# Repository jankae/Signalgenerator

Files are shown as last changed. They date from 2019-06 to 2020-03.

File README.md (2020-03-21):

# Signalgenerator

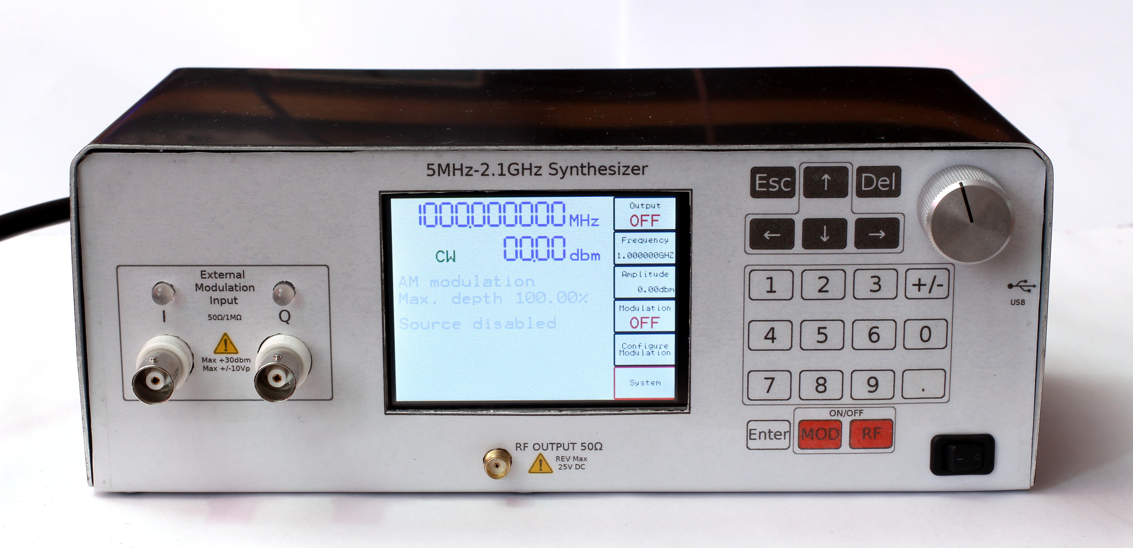
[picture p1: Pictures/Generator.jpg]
Generator


## What is it?
A homemade RF signal generator with these features:
* Frequency range: 5MHz to 2.1GHz
* Amplitude range: approx. -40dbm to +15dbm (slightly frequency dependent)
* Modulation
  * AM
  * FM
    * Up to 12.5MHz frequency deviation
  * QAM
    * Up to 32 constellation points
    * Up to 33M samples per second
    * Up to 36 samples per symbol
    * Pulse-shaping and differential encoding
  * External I/Q inputs
    * AC/DC coupling
    * Up to +30dbm/10Vpk input
    * Up to 10MHz of bandwidth
* Spectral purity@+10dbm:
  * Harmonic:
    * f >= 150MHz: <-30dbc
    * f >= 10MHz: <-25dbc
    * f < 10MHz: <-15dbc
  * Non-harmonic:
    * <-50dbc (limited by noise floor for lower output power)
  * Phase noise:
    * <-80dbc/Hz@10kHz offset

## Why was it build?
* Gain experience with RF circuit design
* Unwilling to pay the price for commercial generators (of course this one can't compete with a commercial one but should be good enough for simple RF experiments)

## How does it work?
For a high level overview see the description of the [RF generation](Documentation/RF.md).
For the effect of RF shielding see [these](Documentation/Shielding.md) measurements.

## More Pictures:
The inside: (I reused the frontpanel PCB from [this](https://github.com/jankae/battery-sim) project)
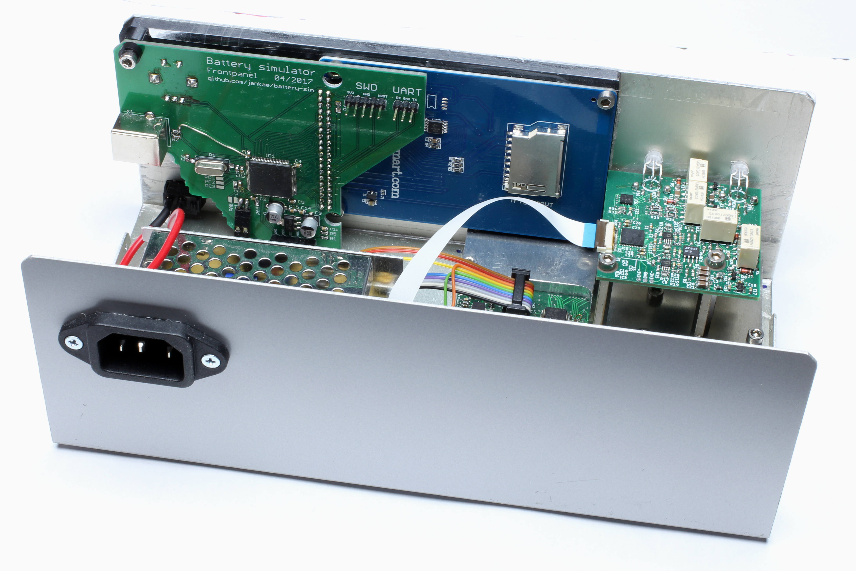
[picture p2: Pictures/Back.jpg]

The external modulation input PCB:
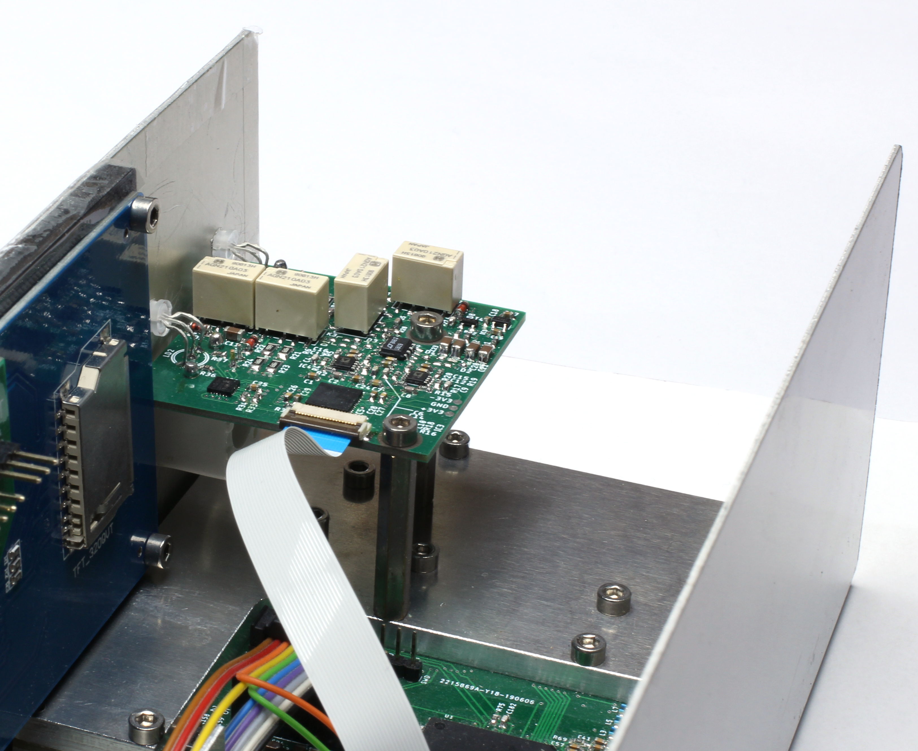
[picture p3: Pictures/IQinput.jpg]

The main RF board:


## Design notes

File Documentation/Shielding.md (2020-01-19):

# Shielding
The critical sections of the RF board are covered by a machined aluminium shield:
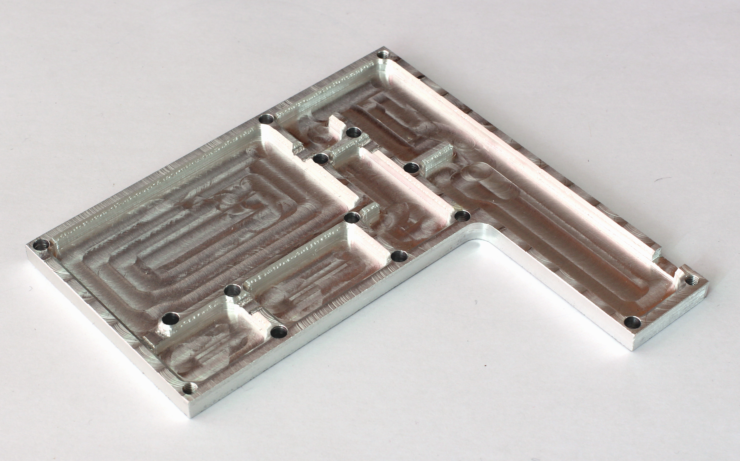
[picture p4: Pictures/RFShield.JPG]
RFshield

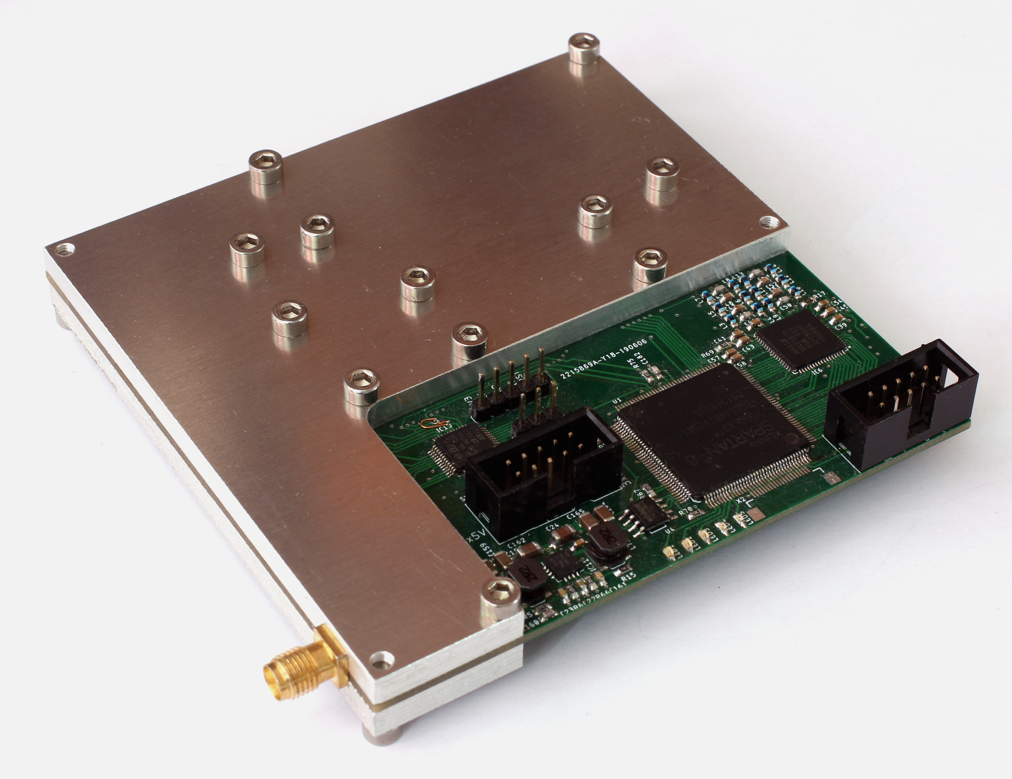
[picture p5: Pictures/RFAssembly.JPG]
RFassembly


The shield is supposed to block external RF from entering the signal generation, prevent emission of unwanted RF signals and shield the different sections from each other. Despite not having RF gaskets and thus probably not the best contact to the PCB ground, it improved the output signal quality significantly, especially unwanted tones when the output attenuation was high.

In the following measurements, the cyan trace shows the output signal without the shield, the yellow trace with the shield:
### 1GHz@0dbm:
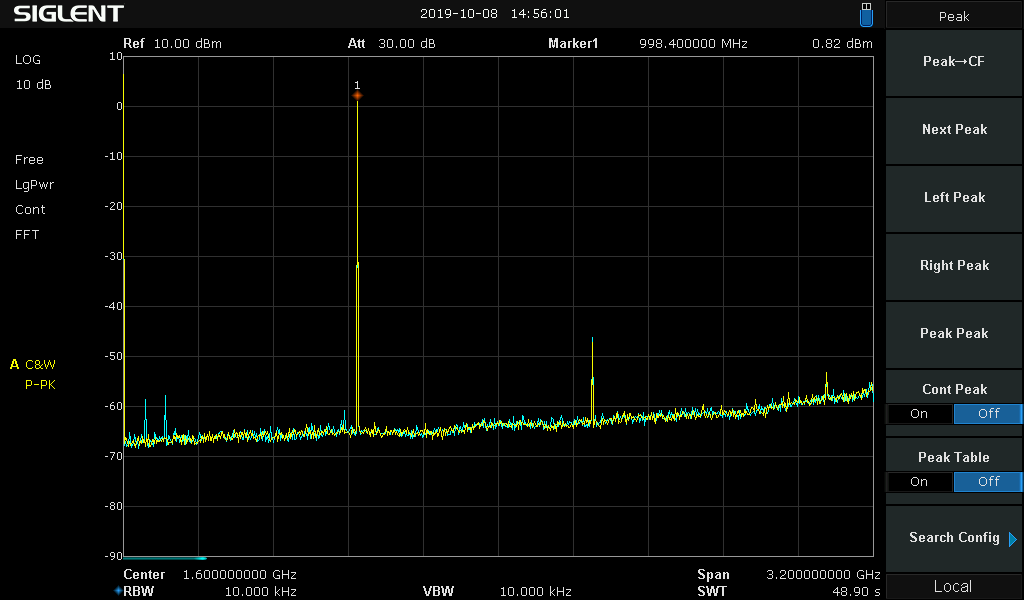
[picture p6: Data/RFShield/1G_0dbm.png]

If you zoom in, the phasenoise also improved slightly:
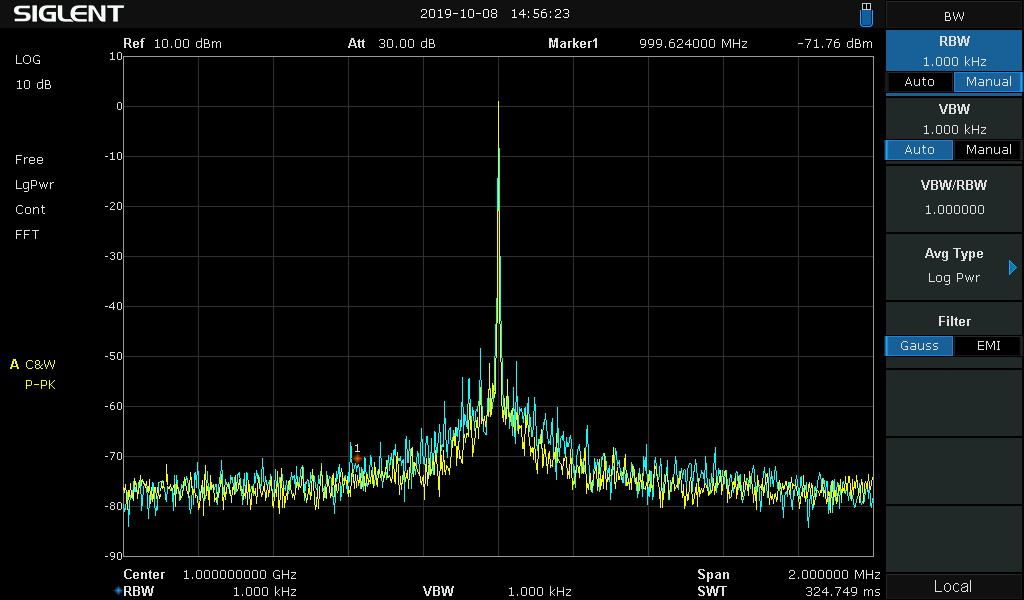
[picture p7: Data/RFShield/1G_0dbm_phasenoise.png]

### 1GHz@-30dbm:
The shield removes quite a few unwanted tones.
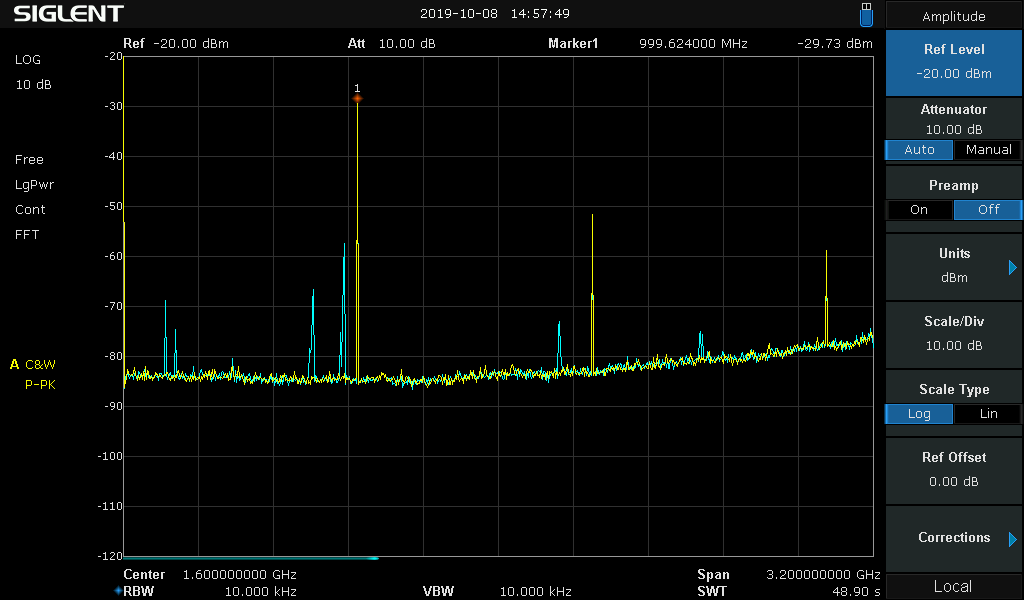
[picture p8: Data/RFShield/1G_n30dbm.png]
1G-30

### 100MHz@+10dbm:
Not much improvement here, the output driver already distorts quite a bit at this frequency and power.
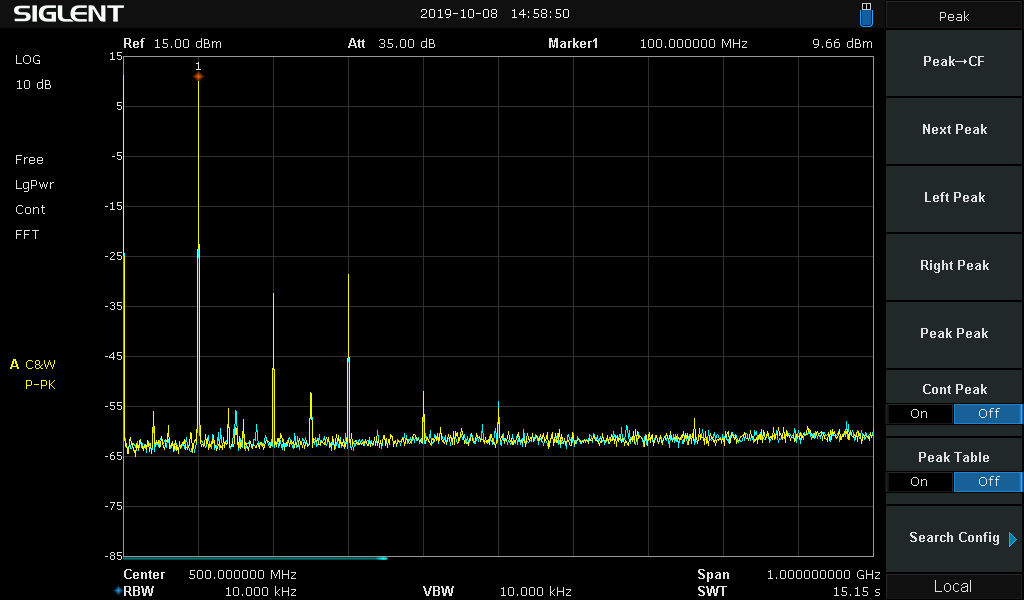
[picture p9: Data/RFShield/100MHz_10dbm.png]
100M+10

### 100MHz@-10dbm:
Again, the shield removes unwanted tones.
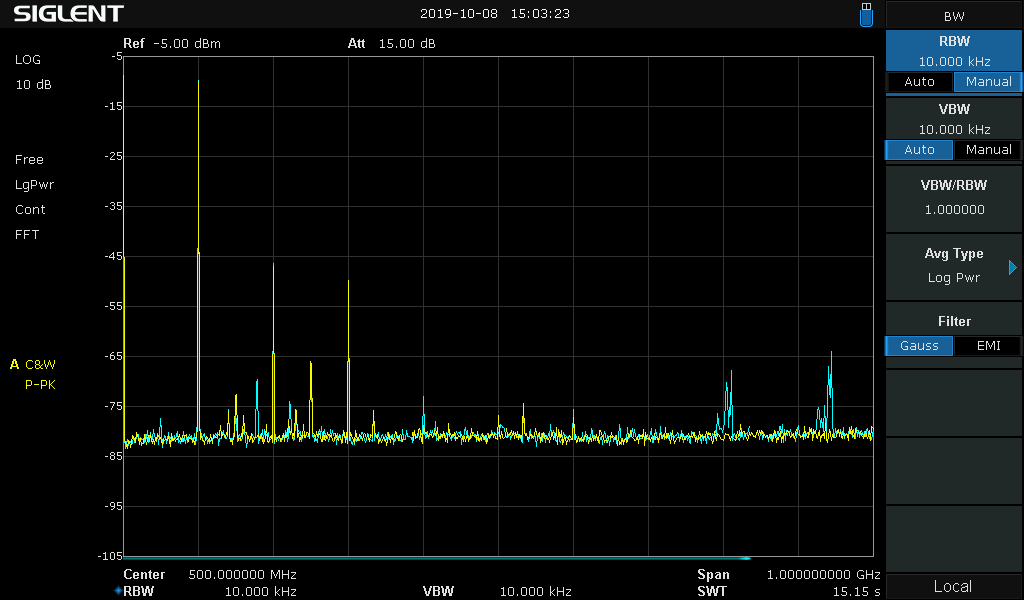
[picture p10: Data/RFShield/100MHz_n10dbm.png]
100M-10

### 100MHz@-30dbm:
Again, the shield removes unwanted tones.
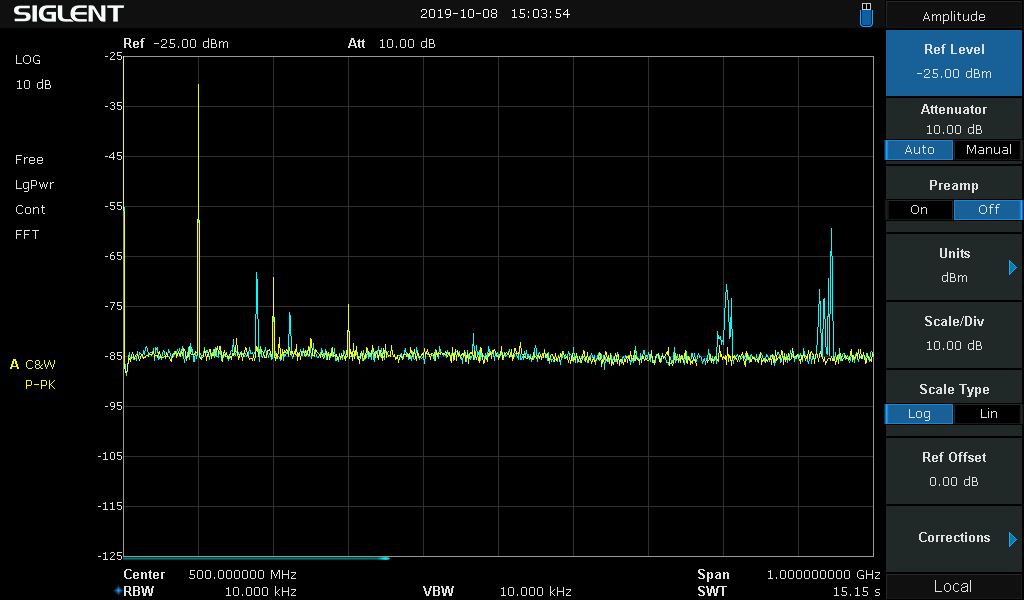
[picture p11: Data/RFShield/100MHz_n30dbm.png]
100M-30

### Output disabled:
Even with the output switched off, the noisefloor is not especially good. This is probably caused by the output amplifiers that are directly connected to the output (any attenuation is done before the final amplification).

During this measurement all PLLs, mixers and RF switches were turned off. The generated tones with no shield are external RF signals that are amplified by the output amplifier.
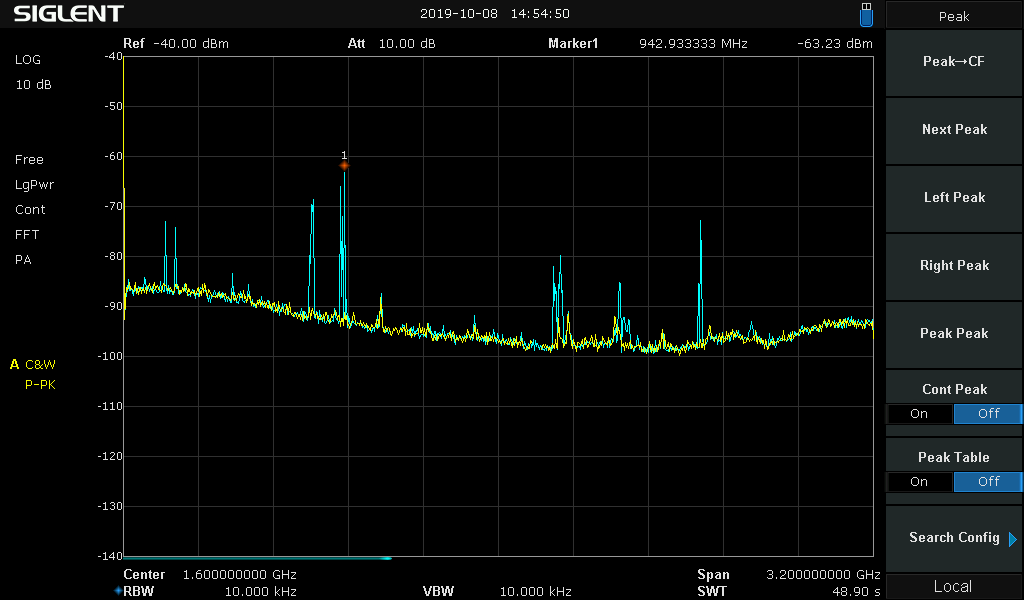
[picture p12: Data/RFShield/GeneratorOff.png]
output_off


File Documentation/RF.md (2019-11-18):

# RF Section
How does the synthesizer generate its signal? First, a blockdiagram of the RF section:
Blockdiagram of RF generation
The signal starts all the way on the left with the main PLL (MAX2871) which generates a sine wave with a frequency range of 250MHz to 2.1GHz. At the next stage some modulation is applied to the signal. In this case a HMC1097 I/Q modulator is used, which contains both mixers as well as the +/-45° phase shift of the carrier. The I/Q inputs are fed by a DAC which gets its signal from an FPGA. This configuration allows to generate pretty much any modulation desired.
After the modulation the signal is passed through a filter bank. Why is that necessary? The MAX2871 doesn't have a VCO covering the whole frequency range. Instead it divides down the VCO for lower output frequencies. This means there are a lot of harmonics still present in the signal. A filter is required that removes these harmonics. As the signal frequency can be changed instead of one filter a whole filter bank is needed.
How many filters are required? Assuming ideal lowpass filters, each filter could cover a frequency range of f to just below 2*f. Any wider and the second harmonic at f would also pass through. For this snythesizer this would mean four filters:

* 500MHz lowpass for 250MHz<=f<500MHz
* 1000MHz lowpass for 500MHz<=f<1000MHz
* 2000MHz lowpass for 1000MHz<=f<2000MHz
* 4000MHz lowpass for 2000MHz<=f<2100MHz

However, actual lowpass filters have a transition band in which the attenuation is low. The cutoff-frequency of each filter must therefor be quite a bit below the lowest possible second harmonic, leading to six filters for this design.
The number of filters is also the reason why the main PLL only goes down to 250MHz. Both the MAX2871 and the HMC1097 could handle lower frequencies, but that would require significantly more filters. Instead the signal is mixed with a fixed frequency of 1GHz from a second PLL for frequencies below 250MHz. In this case the main PLL is set to 1GHz above the actual output frequency . For example, a 100MHz output signal would be generated by setting the main PLL to 1.1GHz. After filtering the signal is down converted by the second PLL and its mixer to 100MHz. The mixer also produces the sum of the frequencies (in this case 2.1GHz) but this is easily filtered out by the following 250MHz lowpass.

All that is left to do is controlling the output level. Various attenuators before the final output amplifier stage are controlled by a microcontroller. Right at the output the signal is split and the weaker part of it fed back into a detector which is sampled by the microcontroller. This closes the level control loop (Initially a analog output level control with an opamp was used. This was actually faster and easier than the digital solution but didn't work well in combination with amplitude modulation. The level control circuit would try to compensate for the amplitude changes from the modulation).

The signal path can also be followed on this PCB overlay:
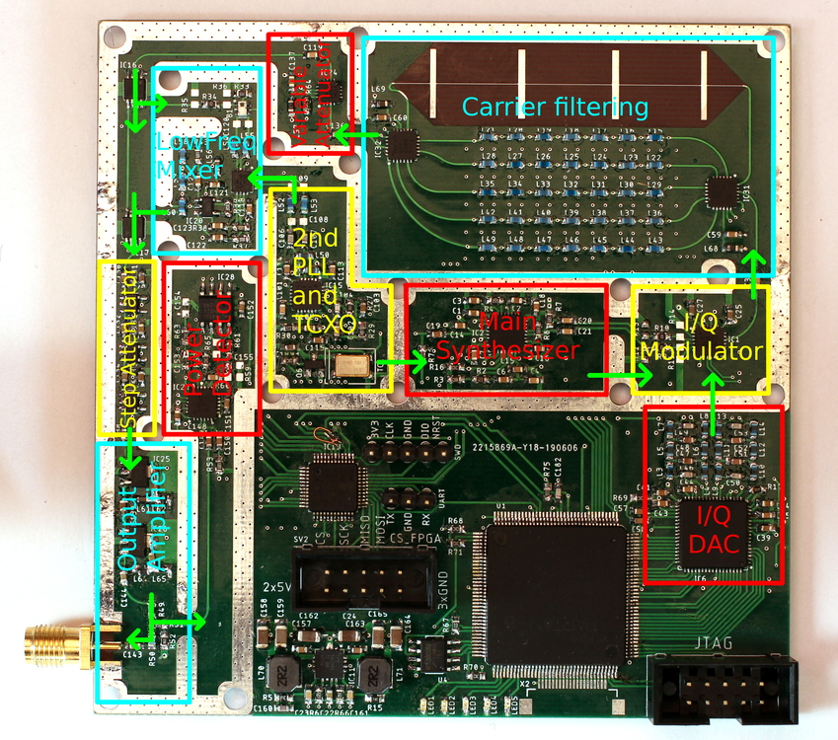
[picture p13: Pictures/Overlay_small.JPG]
RFOverlay


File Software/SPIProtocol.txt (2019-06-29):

Frontpanel to RF board:
0-7: Frequency in Hz, uint64_t. 0 if output disabled.
8-9: Amplitude in 1/100 dbm, int16_t.
10-11: Status bits, uint16_t.
        0x0001: Use internal reference
        0xFFFE: reserved
12-31: reserved

RF board to Frontpanel:
0-1: Status bits, uint16_t.
        0x0001: Internal reference on
        0x0002: Main PLL on
        0x0004: Unlock main PLL
        0x0008: Heterodyne PLL on
        0x0010: Unlock heterodyne PLL
        0x0020: I/Q Modulator enabled
        0x01C0: Selected Filter:
            000: 340MHz
            001: 500MHz
            010: 750MHz
            011: 1.1GHz
            100: 1.7GHz
            101: 2.5GHz
            110-111: reserved
        0x0200: 1st 15dbm attenuator enabled
        0x0400: 2nd 15dbm attenuator enabled
        0x0800: 3rd 15dbm attenuator enabled
        0x1000: Amplitude unlevel
        0xE000: reserved
2-3: reserved
4-7: 0xAE795C0D, magic constant to check communication
8-31: reserved

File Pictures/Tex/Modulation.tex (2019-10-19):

\documentclass[border=10pt]{standalone}  
\usepackage{tikz}
\usepackage[american,siunitx]{circuitikzgit}
\usetikzlibrary{arrows,calc,positioning,decorations.markings}

\newcommand{\divider}[1] 
{  % #1 = name 
\begin{scope}[transform shape]
\draw[thick] (#1)node[](a){} +(-12pt,-12pt) rectangle +(12pt,12pt);
\draw (a)+(12pt, 12pt)--+(-12pt,-12pt);
\draw (a)+(-5pt,6pt) node[](){\footnotesize -45};
\draw (a)+(4pt,-7pt) node[](){\footnotesize +45};
\end{scope}
}

\newcommand{\buswidth}[4][]{\draw (#2) node [#4=.6ex,#1] {#3} +(45:-.8ex) -- +(45:.8ex)}

\makeatletter
%%%% new anchors: "out A" and "out B"
\expandafter\def\csname pgf@anchor@rectangle@out A\endcsname{% output A: below .east
    \pgf@process{\southwest}%
    \pgf@ya=0.25\pgf@y%
    \pgf@process{\northeast}%
    \pgf@y=0.75\pgf@y%
    \advance\pgf@y by\pgf@ya    }% end of out A
\expandafter\def\csname pgf@anchor@rectangle@out B\endcsname{% output B: above .east
    \pgf@process{\southwest}%
    \pgf@ya=0.75\pgf@y%
    \pgf@process{\northeast}%
    \pgf@y=0.25\pgf@y%
    \advance\pgf@y by\pgf@ya    } % end of out B
\makeatother

\tikzset%
{
splitter/.style = {rectangle, draw, semithick, minimum height=15mm, minimum width=15mm,
                            append after command={\pgfextra{\let\LN\tikzlastnode
     \draw[thick] (\LN.west) -- ([xshift=-4mm] \LN.center)
                             -- ([xshift=-8mm] \LN.out A)
                             -- (\LN.out A)
  ([xshift=-4mm] \LN.center) -- ([xshift=-8mm] \LN.out B)
                             -- (\LN.out B);
    \node[above left=0.35cm and 0cm,font=\footnotesize] at (\LN.east) {\SI{-3}{\decibel}};
    \node[below left=0.35cm and 0cm,font=\footnotesize] at (\LN.east) {\SI{-12}{\decibel}};
                                                }}
                        },
         splitter/.default = {},
buswidth/.style n args={2}{
postaction=decorate,
decoration={
  markings,
  mark={at position 0.5 with {\node[rotate=45, font=\footnotesize] {|};}},
  mark={at position 0.5 with {\node[#2=0.15cm, font=\footnotesize] {#1};}}
  }
},
}

\begin{document}  

\begin{circuitikz}

\draw (0,0)coordinate (muxll)--++(20:2.5)coordinate (muxlr)--++(90:18)coordinate (muxur)--++(160:2.5)coordinate (muxul)--cycle;
\draw[-latex,buswidth={12}{below}] ($(muxur)!0.45!(muxlr)$)--++(0:1)node[right]{$I$};
\draw[-latex,buswidth={12}{below}] ($(muxur)!0.55!(muxlr)$)--++(0:1)node[right]{$Q$};

\draw[latex-] ($(muxur)!0.5!(muxul)$)--++(0,0.5)node[above]{Modulation};
% No modulation
\draw ($(muxul)!1.5/19!(muxll)$)node[right, align=left]{Modulation\\disabled};
\draw[latex-] ($(muxul)!1/19!(muxll)$)--++(180:1)node[left]{1};
\draw[latex-] ($(muxul)!2/19!(muxll)$)--++(180:1)node[left]{0};
% AM
\draw ($(muxul)!5.5/19!(muxll)$)node[right]{AM};
\draw[latex-] ($(muxul)!6/19!(muxll)$)--++(180:1)node[left]{0};
\path ($(muxul)!5/19!(muxll)$)--++(180:2)coordinate (amadder);
\node[adder](amadd) at (amadder){};
\draw[-latex,buswidth={12}{below}](amadd.east)--($(muxul)!5/19!(muxll)$);
\draw[latex-](amadd.north)node[above=0.2cm, left]{-}--++(0,1)node[above]{1};
\path (amadder)--++(180:2)coordinate (ammultiplier);
\node[mixer](ammult) at (ammultiplier){};
\draw[-latex,buswidth={12}{below}](ammult.east)--(amadd.west);
\draw[latex-,buswidth={16}{left}](ammult.north)--++(0,1)node[above]{Depth};
% FM
\draw ($(muxul)!9.5/19!(muxll)$)node[right](modmuxfm){FM};
\draw[latex-, buswidth={12}{below}] ($(muxul)!10/19!(muxll)$)--++(-2,0)coordinate(fmmuxout);
\draw(fmmuxout)--++(0,0.2)--++(160:0.8)coordinate(fmmuxul)--++(-90:2)coordinate(fmmuxll)--++(20:0.8)coordinate(fmmuxlr)--(fmmuxout);
\draw[latex-]($(fmmuxll)!0.5!(fmmuxlr)$)--++(0,-0.5)node[below]{SSB};
\node[draw,minimum width=2cm,minimum height=3cm,above left=1.2 and 4,anchor=north east](fmdds) at (modmuxfm){};
\node[below] at (fmdds.north){DDS};
\draw[latex-, buswidth={12}{below}] ($(muxul)!9/19!(muxll)$)coordinate(modmuxfmi)--(fmdds.east|-modmuxfmi)node[left,font=\footnotesize]{sin};
\draw[latex-]($(fmmuxul)!1/4!(fmmuxll)$)--++(-0.5,0)coordinate(fmmux0);
\draw(fmmux0) to[short, -*] (fmmux0|-modmuxfmi);
\draw[latex-] ($(fmmuxul)!2/4!(fmmuxll)$)coordinate(fmmux1)--(fmdds.east|-fmmux1)node[left,font=\footnotesize]{cos};
\draw[latex-] ($(fmmuxul)!3/4!(fmmuxll)$)coordinate(fmmux2)--(fmdds.east|-fmmux2)node[left,font=\footnotesize]{-cos};
\path (fmdds.west|-modmuxfmi)--++(180:2)coordinate (fmmultiplier);
\node[mixer](fmmult) at (fmmultiplier){};
\draw[-latex,buswidth={32}{below}](fmmult.east)--(fmmult.east-|fmdds.west)node[right,font=\footnotesize]{pinc};
\draw[latex-,buswidth={16}{left}](fmmult.north)--++(0,1)node[above]{Deviation};
% I/Q
\draw ($(muxul)!13.5/19!(muxll)$)node[right](modmuxiq){I/Q};
\draw[latex-,buswidth={12}{below}]($(muxul)!13/19!(muxll)$)coordinate(modmuxiqi)--++(-2,0);
\draw[latex-,buswidth={12}{below}]($(muxul)!14/19!(muxll)$)coordinate(modmuxiqq)--++(-2,0);
\node[draw,minimum width=1cm,minimum height=0.5cm,left=2,anchor=east](iqfiri) at (modmuxiqi){FIR};
\node[draw,minimum width=1cm,minimum height=0.5cm,left=2,anchor=east](iqfirq) at (modmuxiqq){FIR};
\node[draw,minimum width=2cm,minimum height=2cm,left=5,anchor=east](iqlut) at (modmuxiq){LUT};
\draw[latex-](iqlut.south)--++(0,-0.5)node[below]{Constellation};
\draw[latex-](iqfiri.west)--(iqlut.east|-iqfiri.west);
\draw[latex-](iqfirq.west)--(iqlut.east|-iqfirq.west);
\node[american and port,left=2](iqand) at (iqlut){};
\draw[-latex, buswidth={8}{below}](iqand.east)--(iqlut.west);
\node[left] at (iqand.in 2){Bits/symbol};
 \node[draw,dashed,minimum width=1.8cm,minimum height=2cm,left=2,anchor=east](pulse) at (modmuxiq){};
\node[below,align=center] at(pulse.south){Pulse\\shaping};
% External modulation
\draw ($(muxul)!17.5/19!(muxll)$)node[right, align=left]{External\\modulation};
\draw ($(muxul)!13.5/19!(muxll)$)node[right](modmuxiq){I/Q};
\draw[latex-,buswidth={12}{below}]($(muxul)!17/19!(muxll)$)coordinate(modmuxexti)--++(-2,0);
\draw[latex-,buswidth={12}{below}]($(muxul)!18/19!(muxll)$)coordinate(modmuxextq)--++(-2,0);
\node[draw,minimum width=1cm,minimum height=0.5cm,left=2,anchor=east](extfiri) at (modmuxexti){FIR};
\node[draw,minimum width=1cm,minimum height=0.5cm,left=2,anchor=east](extfirq) at (modmuxextq){FIR};
\node[left=2,anchor=east](extadci) at (extfiri){};
\node[left=2,anchor=east](extadcq) at (extfirq){};
\draw (extadci) to[dac] ++(-1,0);
\draw (extadcq) to[dac] ++(-1,0);
\draw[latex-, buswidth={10}{below}](extfiri.west)--++(-1.63,0);
\draw[latex-, buswidth={10}{below}](extfirq.west)--++(-1.63,0);
% Source
\draw[latex-](ammult.west)--++(-5,0)coordinate(src);
\draw[buswidth={12}{below}](src)--++(-3,0)node[left]{Source};
\draw[latex-](fmmult.west)--(fmmult.west-|src)coordinate(src2);
\draw (src2) to[short,-*](src);

\draw(iqand.in 1)--(iqand.in 1-|src2);
\draw (iqand.in 1-|src2) to[short,-*](src2);
%\draw ($(O)!0.5!(A)$)--++(-90:1)--++(180:2)node[left]{$b$};
%\draw ($(O)!0.25!(A)$)--++(-90:0.5)--++(180:1.75)node[left]{$a$};
%\draw ($(O)!0.75!(A)$)--++(-90:1.5)--++(180:2.25)node[left]{$c$};
%\foreach \y/\t in {0.1/1,0.2/2,0.3/3,0.4/4,0.5/5,0.6/6,0.7/7,0.8/8} {
%\draw ($(C)! \y*1.1 !(O)$)--++(180:1) node[left] {$X \t$};}
\end{circuitikz}
\end{document}

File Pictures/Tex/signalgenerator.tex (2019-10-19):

\documentclass[border=10pt]{standalone}  
\usepackage{tikz}
\usepackage[american,siunitx]{circuitikzgit}
\usetikzlibrary{arrows,calc,positioning}

\newcommand{\divider}[1] 
{  % #1 = name 
\begin{scope}[transform shape]
\draw[thick] (#1)node[](a){} +(-12pt,-12pt) rectangle +(12pt,12pt);
\draw (a)+(12pt, 12pt)--+(-12pt,-12pt);
\draw (a)+(-5pt,6pt) node[](){\footnotesize -45};
\draw (a)+(4pt,-7pt) node[](){\footnotesize +45};
\end{scope}
}

\makeatletter
%%%% new anchors: "out A" and "out B"
\expandafter\def\csname pgf@anchor@rectangle@out A\endcsname{% output A: below .east
    \pgf@process{\southwest}%
    \pgf@ya=0.25\pgf@y%
    \pgf@process{\northeast}%
    \pgf@y=0.75\pgf@y%
    \advance\pgf@y by\pgf@ya    }% end of out A
\expandafter\def\csname pgf@anchor@rectangle@out B\endcsname{% output B: above .east
    \pgf@process{\southwest}%
    \pgf@ya=0.75\pgf@y%
    \pgf@process{\northeast}%
    \pgf@y=0.25\pgf@y%
    \advance\pgf@y by\pgf@ya    } % end of out B
\makeatother

\tikzset%
{
splitter/.style = {rectangle, draw, semithick, minimum height=15mm, minimum width=15mm,
                            append after command={\pgfextra{\let\LN\tikzlastnode
     \draw[thick] (\LN.west) -- ([xshift=-4mm] \LN.center)
                             -- ([xshift=-8mm] \LN.out A)
                             -- (\LN.out A)
  ([xshift=-4mm] \LN.center) -- ([xshift=-8mm] \LN.out B)
                             -- (\LN.out B);
    \node[above left=0.35cm and 0cm,font=\footnotesize] at (\LN.east) {\SI{-3}{\decibel}};
    \node[below left=0.35cm and 0cm,font=\footnotesize] at (\LN.east) {\SI{-12}{\decibel}};
                                                }}
                        },
         splitter/.default = {}
}

\begin{document}  

\begin{circuitikz}
%\node[lowpass]{};
% VCO + 90 degree splitter
\path (0,0) node[](synth) {} to[vco]node[above=0.5cm](){\SI{250}{\mega\hertz} to \SI{2.1}{\giga\hertz}} (0,0);
\path (2,0) node[](){} to[box]node(div){}(3,0);
\divider{div}
\draw[-latex] (synth)++(0.5,0)--++(1.57,0);
% I/Q mixer
\draw (4,1) node[mixer](mixeri){};
\draw (6,-1) node[mixer](mixerq){};
\draw[-latex] (div)++(0,12pt)|-(mixeri.west);
\draw[-latex] (div)++(0,-12pt)|-(mixerq.west);
\draw (7,0) node[adder](add){};
\draw[-latex] (mixeri.east)-|(add.north);
\draw[-latex] (mixerq.east)-|(add.south);
% I/Q DAC + filters
\draw (4,-4.5) to[dac, n=daci] (4,-3.5);
\draw[-latex] (4,-3) to[lowpass, n=lpfi] (4,-2) -- (mixeri.south);
\node[rotate=90] at (3.3,-2.5) {\SI{50}{\mega\hertz}};
\draw[-latex] (daci)++(0,0.5)--++(0,0.5);
\draw (6,-4.5) to[dac, n=dacq] (6,-3.5);
\draw[-latex] (6,-3) to[lowpass, n=lpfq] (6,-2) -- (mixerq.south);
\node[rotate=90] at (5.3,-2.5) {\SI{50}{\mega\hertz}};
\draw[-latex] (dacq)++(0,0.5)--++(0,0.5);

% rotary switches and filter bank
\draw (add.east) -- ++(0.5,0)
    node[rotary switch <->=6 in 60 wiper 60, anchor=in](swfiltin){};
\draw (14.5,0) -- ++(-0.5,0)
    node[rotary switch <->=6 in 60 wiper 60, anchor=in, xscale = -1](swfiltout){};

\draw (swfiltin.out 1) -| (9, 3) --  (10,3) to[lowpass, l=\SI{340}{\mega\hertz}] ++(2,0) -- ++(1,0) |- (swfiltout.out 1);
\draw (swfiltin.out 2) -| (9.5, 1.5) --  (10,1.5) to[lowpass, l=\SI{500}{\mega\hertz}] ++(2,0) -- ++(0.5,0) |- (swfiltout.out 2);
\draw (swfiltin.out 3) -| (10, 0) --  (10,0) to[lowpass, l=\SI{750}{\mega\hertz}] ++(2,0) -- ++(0,0) |- (swfiltout.out 3);
\draw (swfiltin.out 4) -| (9.5, -1.5) --  (10,-1.5) to[lowpass, l=\SI{1.1}{\giga\hertz}] ++(2,0) -- ++(0.5,0) |- (swfiltout.out 4);
\draw (swfiltin.out 5) -| (9, -3) --  (10,-3) to[lowpass, l=\SI{1.7}{\giga\hertz}] ++(2,0) -- ++(1,0) |- (swfiltout.out 5);
\draw (swfiltin.out 6) -| (8.5, -4.5) --  (10,-4.5) to[lowpass, l=\SI{2.5}{\giga\hertz}] ++(2,0) -- ++(1.5,0) |- (swfiltout.out 6);

\node[spdt](switchin) at (17,0) {};
\node[spdt, xscale=-1](switchout) at (23,0) {};
\draw (swfiltout.in) to[vpiattenuator] (switchin.in);
\draw (switchin.out 1)--(switchout.out 1);
\draw (switchin.out 2)++(1,0) node[mixer](mixhet){};
\draw[-latex] (switchin.out 2)--(mixhet.west);
\draw (mixhet.east) to[amp] ++(2,0) to[lowpass, l_=\SI{250}{\mega\hertz}] (switchout.out 2);
\path (mixhet)++(0,-2) to[vco]node[below=0.5cm](){\SI{1}{\giga\hertz}} ++(0,0);
\draw[latex-] (mixhet.south)--++(0,-1);

\node[splitter=\SI{-3}{\decibel},label={[align=center]Resistive\\splitter}] (s) at (29,0) {};
\draw (switchout.in) to[vpiattenuator] ++(1.5,0) to[amp] ++(1.5,0) to[amp] (s.west);
\node[align=center] at (24.3,1) {\SIrange{0}{-45}{\decibel}\\in \SI{15}{\decibel} steps} ;

\draw (15.2,-4.5) to[dac, n=daclvl] (15.2,-3.5);
\draw[-latex] (15.2,-3.5) to (15.2,-0.5);

%\node[op amp, xscale=-1, yscale=-1](levelctrl) at (21,-3.5) {};
\draw[-latex] (s.out B) -| ++(0.5,-1) to[detector] ++(0,-2.13);
\draw (30.26,-4.5) to[adc, n=adc] (30.26,-3.5);

%\draw (levelctrl.-)node[right]{Output amplitude setpoint};
%\draw[-latex, dashed] (levelctrl.out) -| (15.2,-0.5);
\draw[-o] (s.out A)--++(0.5,0)node[right]{Output};
\end{circuitikz}
\end{document}

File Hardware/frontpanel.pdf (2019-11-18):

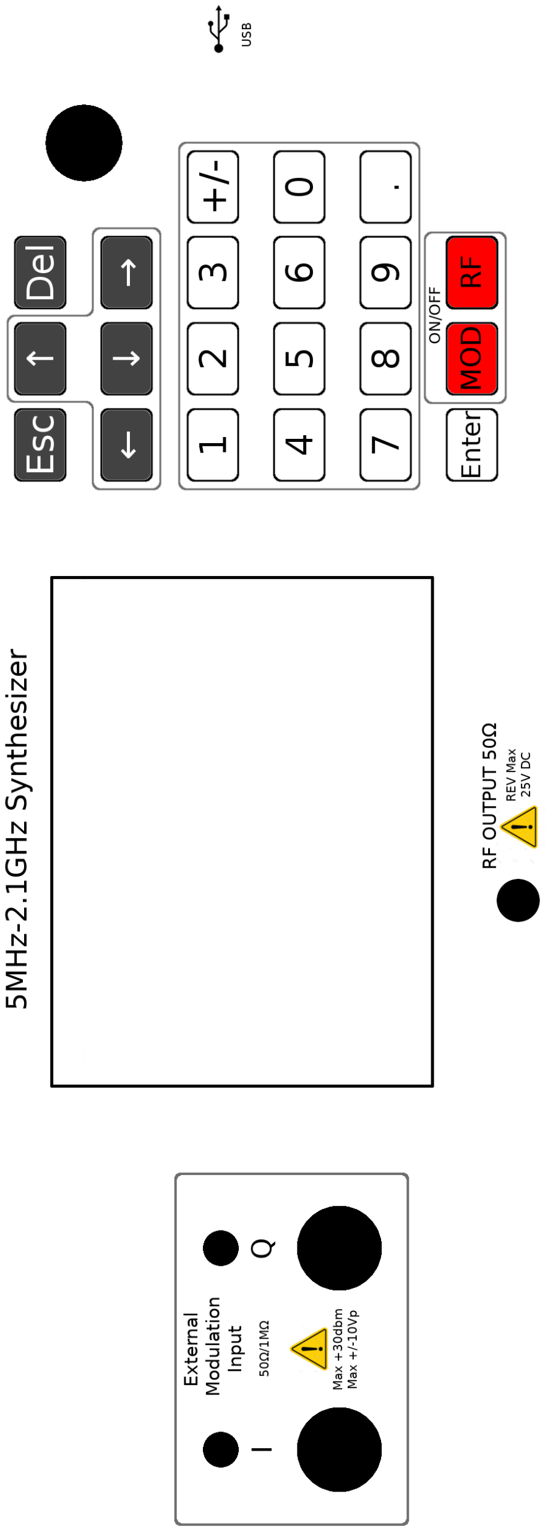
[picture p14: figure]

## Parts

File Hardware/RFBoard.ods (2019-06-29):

Qty | Value | Device | Package | Parts | Description | Mouser | MANUFACTURER | MF | MPN | OC_FARNELL | OC_NEWARK | PACKAGE | SUPPLIER
7 |  | L-EUL2012C | L2012C | L1, L2, L56, L57, L67, L68, L69 | INDUCTOR, European symbol | MPZ1608S601ATA00 (https://www.mouser.de/ProductDetail/TDK/MPZ1608S601ATA00)
5 |  | LEDCHIP-LED0603 | CHIP-LED0603 | LED1, LED2, LED3, LED4, LED5 | LED
2 |  | ML10 | ML10 | JTAG, SV2 | HARTING |  |  |  |  | unknown | unknown
1 |  | PINHD-1X3 | 1X03 | UART | PIN HEADER
1 |  | PINHD-1X5 | 1X05 | SWD | PIN HEADER
6 | 0 | R-EU_R0603 | R0603 | R2, R9, R10, R34, R47, R48 | RESISTOR, European symbol
1 | 1.91k | R-EU_R0603 | R0603 | R17 | RESISTOR, European symbol
43 | 100n | C-EUC0603 | C0603 | C6, C7, C14, C15, C16, C18, C19, C39, C40, C41, C42, C43, C44, C45, C57, C58, C59, C60, C103, C113, C114, C115, C118, C157, C163, C166, C167, C168, C169, C170, C171, C172, C173, C174, C175, C176, C177, C178, C179, C180, C181, C183, C184 | CAPACITOR, European symbol
2 | 100n | INDUCTOR0603 | R0603 | L50, L51
2 | 100p | C-EUC0603 | C0603 | C140, C145 | CAPACITOR, European symbol
23 | 10k | R-EU_R0603 | R0603 | R16, R31, R32, R44, R45, R46, R54, R55, R56, R57, R58, R61, R62, R63, R64, R68, R69, R70, R71, R72, R73, R74, R77 | RESISTOR, European symbol
10 | 10n | C-EUC0603 | C0603 | C20, C21, C23, C30, C101, C119, C136, C141, C146, C161 | CAPACITOR, European symbol
3 | 10u | C-EUC0603 | C0603 | C55, C105, C110 | CAPACITOR, European symbol
7 | 10u | C-EUC1206 | C1206 | C12, C13, C24, C26, C28, C29, C162 | CAPACITOR, European symbol
1 | 110 | R-EU_R0603 | R0603 | R51 | RESISTOR, European symbol
7 | 12 | INDUCTOR0603 | R0603 | L29, L30, L31, L32, L33, L34, L35
2 | 120 | R-EU_R0603 | R0603 | R3, R29 | RESISTOR, European symbol
1 | 12n | C-EUC0603 | C0603 | C4 | CAPACITOR, European symbol
8 | 14p | C-EUC0603 | C0603 | C69, C70, C79, C80, C81, C82, C83, C84 | CAPACITOR, European symbol
4 | 15p | C-EUC0603 | C0603 | C46, C49, C50, C53 | CAPACITOR, European symbol
7 | 18 | INDUCTOR0603 | R0603 | L22, L23, L24, L25, L26, L27, L28
3 | 1n | C-EUC0603 | C0603 | C25, C27, C151 | CAPACITOR, European symbol
49 | 1u | C-EUC0603 | C0603 | C1, C2, C3, C8, C9, C10, C11, C17, C22, C31, C32, C33, C34, C35, C36, C37, C38, C54, C56, C111, C112, C116, C117, C121, C122, C123, C124, C125, C130, C131, C132, C133, C134, C135, C137, C138, C139, C142, C143, C144, C147, C148, C149, C150, C152, C153, C154, C155, C156 | CAPACITOR, European symbol
4 | 200 | R-EU_R0603 | R0603 | R37, R38, R39, R40 | RESISTOR, European symbol
8 | 200n | INDUCTOR0603 | R0603 | L3, L4, L7, L8, L9, L10, L13, L14
8 | 20p | C-EUC0603 | C0603 | C61, C62, C71, C72, C73, C74, C75, C76 | CAPACITOR, European symbol
3 | 22 | R-EU_R0603 | R0603 | R67, R75, R76 | RESISTOR, European symbol
5 | 220 | R-EU_R0603 | R0603 | R78, R79, R80, R81, R82 | RESISTOR, European symbol
2 | 22k1 | R-EU_R0603 | R0603 | R6, R66 | RESISTOR, European symbol
3 | 22p | C-EUC0603 | C0603 | C126, C127, C160 | CAPACITOR, European symbol
4 | 22u | C-EUC1206 | C1206 | C158, C159, C164, C165 | CAPACITOR, European symbol
2 | 250 | R-EU_R0603 | R0603 | R1, R27 | RESISTOR, European symbol
2 | 2u2 | SRN5040 | SRN5040 | L70, L71
1 | 3 | R-EU_R0603 | R0603 | R33 | RESISTOR, European symbol
12 | 30n | INDUCTOR0603 | R0603 | L15, L16, L17, L18, L19, L20, L21, L58, L59, L60, L61, L64
6 | 30p | C-EUC0603 | C0603 | C63, C64, C65, C66, C67, C68 | CAPACITOR, European symbol
4 | 330n | INDUCTOR0603 | R0603 | L5, L6, L11, L12
3 | 33p | C-EUC0603 | C0603 | C128, C129, C182 | CAPACITOR, European symbol
4 | 3n9 | INDUCTOR0603 | R0603 | L52, L53, L54, L55
2 | 3p9 | C-EUC0603 | C0603 | C93, C94 | CAPACITOR, European symbol
2 | 470 | R-EU_R0603 | R0603 | R26, R28 | RESISTOR, European symbol
2 | 470n | INDUCTOR0603 | R0603 | L62, L65
12 | 49R9 | R-EU_R0603 | R0603 | R7, R8, R18, R19, R20, R21, R22, R23, R24, R25, R43, R53 | RESISTOR, European symbol
3 | 4k7 | R-EU_R0603 | R0603 | R30, R41, R42 | RESISTOR, European symbol
1 | 5k1 | R-EU_R0603 | R0603 | R4 | RESISTOR, European symbol
7 | 5n6 | INDUCTOR0603 | R0603 | L43, L44, L45, L46, L47, L48, L49
10 | 5p6 | C-EUC0603 | C0603 | C85, C86, C95, C96, C97, C98, C99, C100, C106, C107 | CAPACITOR, European symbol
4 | 68p | C-EUC0603 | C0603 | C47, C48, C51, C52 | CAPACITOR, European symbol
1 | 6SLX9TQG144 | 6SLX9TQG144 | TQ144 | U1 | Xilinx FPGA: 6SLX9TQG144
2 | 73k2 | R-EU_R0603 | R0603 | R5, R15 | RESISTOR, European symbol
1 | 77R5 | R-EU_R0603 | R0603 | R52 | RESISTOR, European symbol
3 | 820p | C-EUC0603 | C0603 | C5, C102, C104 | CAPACITOR, European symbol
2 | 8R66 | R-EU_R0603 | R0603 | R49, R50 | RESISTOR, European symbol
2 | 8n2 | INDUCTOR0603 | R0603 | L36, L42
5 | 8n7 | INDUCTOR0603 | R0603 | L37, L38, L39, L40, L41
8 | 9p | C-EUC0603 | C0603 | C77, C78, C87, C88, C89, C90, C91, C92 | CAPACITOR, European symbol
1 | ADF4360 | ADF4360 | QFN50P400X400X80-25T230 | IC15 |  | ADF4360-2BCPZRL7 (https://www.mouser.de/ProductDetail/Analog-Devices/ADF4360-2BCPZRL7?qs=sGAEpiMZZMv9Q1JI0Mo%2FtclTGQQ5A2WQ)
1 | AP2114HA-3.3 | AP2114HA | SOT230P700X180-4 | IC3 |  | AP2114H-3.3TRG1 (https://www.mouser.de/ProductDetail/Diodes-Incorporated/AP2114H-33TRG1)
5 | BSS123 | BSS123 | SOT23 | Q1, Q2, Q3, Q4, Q5 | N-CHANNEL MOS FET
1 | BSS84 | BSS84 | SOT23 | Q6 | P-CHANNEL MOS FET
3 | DNP | C-EUC0603 | C0603 | C108, C109, C120 | CAPACITOR, European symbol
9 | DNP | R-EU_R0603 | R0603 | R11, R12, R13, R14, R35, R36, R59, R60, R65 | RESISTOR, European symbol
1 | FH12-20S-0.5SH | FH12-20S-0.5SH | FH12-20S-0.5SH | X2 | 0.5mm Pitch Connectors For FPC/FFC |  |  |  | FH12-20S-0.5SH(55) | 1324549 | 34M6166
1 | HHM1522B1 | HHM1522B1 | INDCAF65P200X125X95-6 | B1 |  | HHM (https://www.mouser.de/TDK/Signal-Conditioning/HHM-Series/_/N-1z0zl82Z8bzuiZ1yzsv32)
1 | HMC1021 | HMC1021 | QFN50P400X400X100-25T270 | IC27 |  | HMC1021LP4E (https://www.mouser.de/ProductDetail/Analog-Devices-Hittite/HMC1021LP4E)
1 | HMC1097 | HMC1097 | QFN50P400X400X100-25T280 | IC1 |  | HMC1097LP4ETR (https://www.mouser.de/ProductDetail/Analog-Devices-Hittite/HMC1097LP4ETR)
2 | HMC284 | HMC284 | MSOP08 | IC16, IC17
1 | LT1395 | OPA344N-SOT23 | SOT23-5 | IC20 | Single Operational Amplifier | LT1395CS5#TRMPBF (https://www.mouser.de/ProductDetail/Analog-Devices/LT1395CS5TRMPBF)
1 | LT5560 | LT5560 | SON50P300X300X80-9T165X238 | IC14 |  | LT5560EDD#PBF (https://www.mouser.de/ProductDetail/Analog-Devices/LT5560EDDPBF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)
3 | MAADSS0008 | MAADSS0008 | SOT95P280X110-5 | IC21, IC22, IC23 |  | MAADSS0008TR-3000 Datenblatt (https://www.mouser.de/datasheet/2/249/MAADSS0008-335694.pdf)
1 | MAX2871 | MAX2871 | QFN50P500X500X80-33T310 | IC2 |  | MAX2871ETJ+ (https://www.mouser.de/ProductDetail/Maxim-Integrated/MAX2871ETJ%2B)
1 | MAX5873 | MAX5873 | QFN50P1000X1000X100-69T770 | IC6 |  | MAX5873EGK+D (https://www.mouser.de/ProductDetail/Maxim-Integrated/MAX5873EGK%2BD)
2 | MCP4812 | MCP4812 | SO08 | IC12, IC28 | 12-Bit Dual Voltage Output Digital-to-Analog Converter | MCP4822T-E/SN (https://www.mouser.de/ProductDetail/Microchip-Technology/MCP4822T-E-SN) |  |  | MCP4822-E/SN | 1834912 |  | SO08 | MICROCHIP
2 | MMG3H21NT1 | HMC480 | SOT89 | IC25, IC26 |  | MMG3H21NT1 (https://www.mouser.de/NXP/RF-Amplifier/MMG3H21NT1-Series/_/N-1z0zl8bZ3ri04Z1yy1bq1)
2 | NCP702-1.8 | NCP702 | SOT95P240X110-5 | IC7, IC10 |  | NCP702SN18T1G (https://www.mouser.de/ProductDetail/ON-Semiconductor/NCP702SN18T1G?qs=sGAEpiMZZMvrYgwxMvI%2FG8elVbATwr5l)
7 | NCP702-3.3 | NCP702 | SOT95P240X110-5 | IC4, IC5, IC8, IC9, IC18, IC19, IC29 |  | NCP702SN33T1G (https://www.mouser.de/ProductDetail/ON-Semiconductor/NCP702SN33T1G?qs=sGAEpiMZZMvrYgwxMvI%2FG%2FOkQPXxkto%2F)
2 | QPC6064 | QPC6064 | QFN50P400X400X75-25T270 | IC31, IC32 |  | QPC6064TR13 (https://www.mouser.de/ProductDetail/Qorvo/QPC6064TR13)
1 | RFSA2033 | RFSA2033 | QFN50P300X300X85-17T170 | IC24 |  | RFSA2033TR7 (https://www.mouser.de/ProductDetail/Qorvo/RFSA2033TR7)
2 | SRU5018-101 | INDUCTOR5018 | SMD5018 | L63, L66 |  | SRU5018-101Y (https://www.mouser.de/ProductDetail/Bourns/SRU5018-101Y)
1 | STM32F030C8T | STM32F030C8T | LQFP48 | IC13 | ARM 32-bit Cortex™-M0 CPU
1 | TCXO-NO-VC-CFPT-127 | TCXO-NO-VC-CFPT-127 | 5.0X3.2-TCXO | TC1 | CRYSTAL RESONATOR | FOX924B-10.000 (https://www.mouser.de/ProductDetail/Fox/FOX924B-10000)
1 | TPS42951 | TPS42951 | QFN65P400X400X100-17T270 | IC11 |  | TPS542951RSAR (https://www.mouser.de/ProductDetail/Texas-Instruments/TPS542951RSAR?qs=sGAEpiMZZMvLNADcllXbqJqEaLVer1SU)
1 | U.FL-R-SMT | U.FL-R-SMT | U.FL_SMT | J1 | U.FL-R-SMT Antenna Connector | H122041-ND | Hirose |  | U.FL-R-SMT-1(01)
1 | W25Q16BVSN | W25Q16BVSN | SO08 | U4 | EEPROM | W25Q16JVSNIQ (https://www.mouser.de/ProductDetail/Winbond/W25Q16JVSNIQ)
1 | out | SMA_CONNECTOR | J502-ND-142-0711-821/826 | X1

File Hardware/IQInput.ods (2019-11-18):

Qty | Value | Device | Package | Parts | Link
2 | 1-1337543-0 | 1-227161-7 | AMP_227161 | X1, X3 | A97553-ND‎ (https://www.digikey.de/product-detail/de/1-1337543-0/A97553-ND/1755940/?itemSeq=307473436)
3 | 100n | C-EUC0603 | C0603 | C1, C7, C25
2 | 100p | C-EUC0603 | C0603 | C2, C8
2 | 10k | R-EU_R0603 | R0603 | R14, R28
5 | 10n | C-EUC0603 | C0603 | C6, C12, C13, C26, C27
6 | 10u | C-EUC1206 | C1206 | C5, C11, C20, C21, C22, C23
2 | 190k | R-EU_R0603 | R0603 | R12, R26 | 311-191KHRCT-ND (https://www.digikey.de/product-detail/de/yageo/RC0603FR-07191KL/311-191KHRCT-ND/729952)
9 | 1u | C-EUC0603 | C0603 | C14, C15, C16, C17, C18, C19, C24, C28, C29
4 | 4148 | DIODE-MINIMELF | MINIMELF | D5, D6, D7, D8
8 | 470 | R-EU_R0603 | R0603 | R3, R4, R5, R6, R17, R18, R19, R20
4 | 49R9 | R-EU_R0603 | R0603 | R1, R2, R15, R16
8 | 49R9 | R-EU_R1206 | R1206 | R7, R8, R9, R10, R21, R22, R23, R24 | 311-49.9FRCT-ND (https://www.digikey.de/product-detail/de/yageo/RC1206FR-0749R9L/311-49.9FRCT-ND/731889)
10 | 4k7 | R-EU_R0603 | R0603 | R29, R30, R31, R32, R33, R34, R36, R37, R38, R39
1 | 51 | R-EU_R0603 | R0603 | R35
2 | 60k | R-EU_R0603 | R0603 | R13, R27 | 311-60.4KHRCT-ND (https://www.digikey.de/product-detail/de/yageo/RC0603FR-0760K4L/311-60.4KHRCT-ND/730275)
2 | 750k | R-EU_R0603 | R0603 | R11, R25 | 311-750KGRCT-ND (https://www.digikey.de/product-detail/de/yageo/RC0603JR-07750KL/311-750KGRCT-ND/729773)
2 | AD8132 | AD8132 | MSOP8 | IC3, IC4 | AD8132WARMZ-R7CT-ND (https://www.digikey.de/product-detail/de/analog-devices-inc/AD8132WARMZ-R7/AD8132WARMZ-R7CT-ND/2091915)
4 | BAV199 | BAV199 | SOT23 | D1, D2, D3, D4 | BAV199-FDICT-ND (https://www.digikey.de/product-detail/de/diodes-incorporated/BAV199-7-F/BAV199-FDICT-ND/1033647)
4 | BC847 | BC847 | SOT23 | T1, T2, T3, T4
4 | DNP | C-EUC0603 | C0603 | C3, C4, C9, C10
1 | FH12-20S-0.5SH | FH12-20S-0.5SH | FH12-20S-0.5SH | X2 | HFJ120CT-ND (https://www.digikey.de/product-detail/de/hirose-electric-co-ltd/FH12-20S-0.5SH-55/HFJ120CT-ND/1110379)
4 | FTR-B4G | FTR-B4G | FTR-B4G | K1, K2, K3, K4 | 255-3356-1-ND (https://www.digikey.de/product-detail/de/panasonic-electric-works/AGN210A03Z/255-3356-1-ND/6187877)
2 | Ferrite | L-EUL2012C | L2012C | L1, L2 | 240-2371-1-ND‎ (https://www.digikey.de/product-detail/de/MI0603J601R-10/240-2371-1-ND/806731/?itemSeq=307474824)
1 | LT1819 | LM358D | SO08 | IC2 | LT1819CS8#PBF-ND (https://www.digikey.de/product-detail/de/linear-technology-analog-devices/LT1819CS8-PBF/LT1819CS8-PBF-ND/889094)
2 | LTL-30EFJ | DUOLED-RG-C | DUOLED-C-5MM | LD1, LD2 | 160-1715-ND‎ (https://www.digikey.de/product-detail/de/LTL-30EFJ/160-1715-ND/670007/?itemSeq=307474441)
1 | MAX19515 | MAX19515 | QFN50P700X700X75-49T550N | IC5 | MAX19515ETM+-ND (https://www.digikey.de/product-detail/de/maxim-integrated/MAX19515ETM/MAX19515ETM-ND/2044673)
1 | PCA9555BS | PCA9555BS | HVQFN24 | IC6 | 568-2382-1-ND (https://www.digikey.de/product-detail/de/nxp-usa-inc/PCA9555BS118/568-2382-1-ND/957608)
1 | TPS60403 | TPS60403 | SOT23-5 | IC1 | 296-27005-1-ND (https://www.digikey.de/product-detail/de/texas-instruments/TPS60403DBVR/296-27005-1-ND/2255295)

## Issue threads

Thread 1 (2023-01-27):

FPGA ID?

samdowrick, 2023-01-27:
Which FPGA did you use  as the part number given "6SLX9TQG144" doesn't exist. Im assuming its a spartan 6?

jankae, 2023-01-30:
Yes, it is a spartan6: XC6SLX9 in the TQFP100 package

samdowrick, 2023-01-31:
Awesome! Is the bit stream for this uploaded through the stm32 or through a jtag dongle?

jankae, 2023-02-01:
You need to use JTAG. I didn't connect the configuration pins of the FPGA to the STM32 in this project.

Closed 2023-02-10.

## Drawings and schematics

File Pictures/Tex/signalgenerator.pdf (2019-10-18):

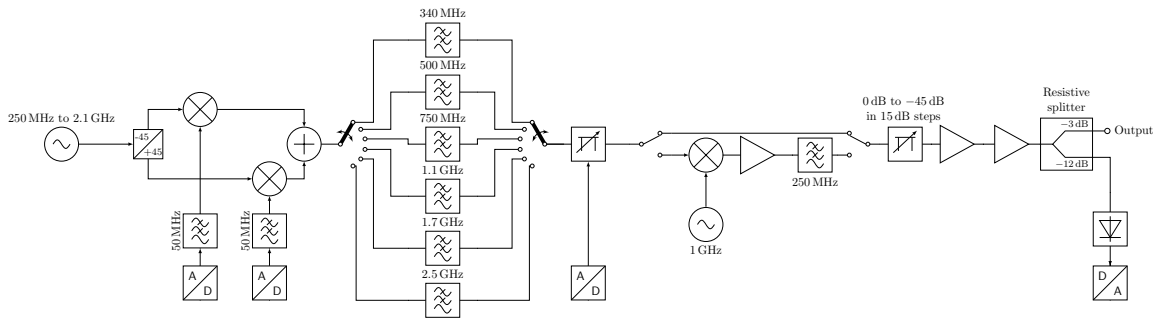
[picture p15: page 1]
250 MHz to 2; .1 GHz; 50 MHz; 340 MHz; 250 MHz; 1 GHz; Resistive; Output

500 MHz
750 MHz 1.1 GHz 1.7 GHz 2.5 GHz

splitter 0 dB to −45 dB
in 15 dB steps

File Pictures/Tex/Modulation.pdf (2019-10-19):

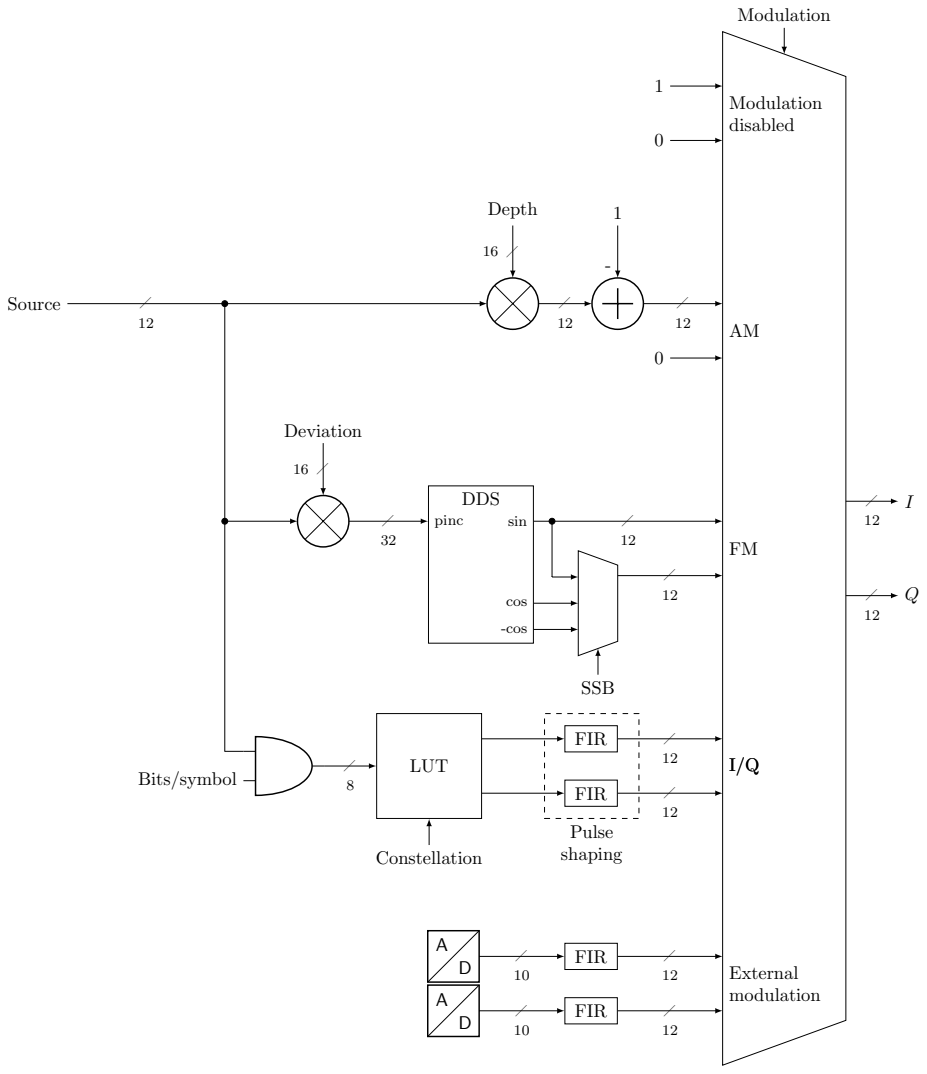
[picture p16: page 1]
Modulation; Modulation disabled; Depth; SSB; DDS; sin; cos; -cos; pinc; Deviation; FIR; LUT; Constellation; Bits/symbol; Pulse shaping; External modulation; Source

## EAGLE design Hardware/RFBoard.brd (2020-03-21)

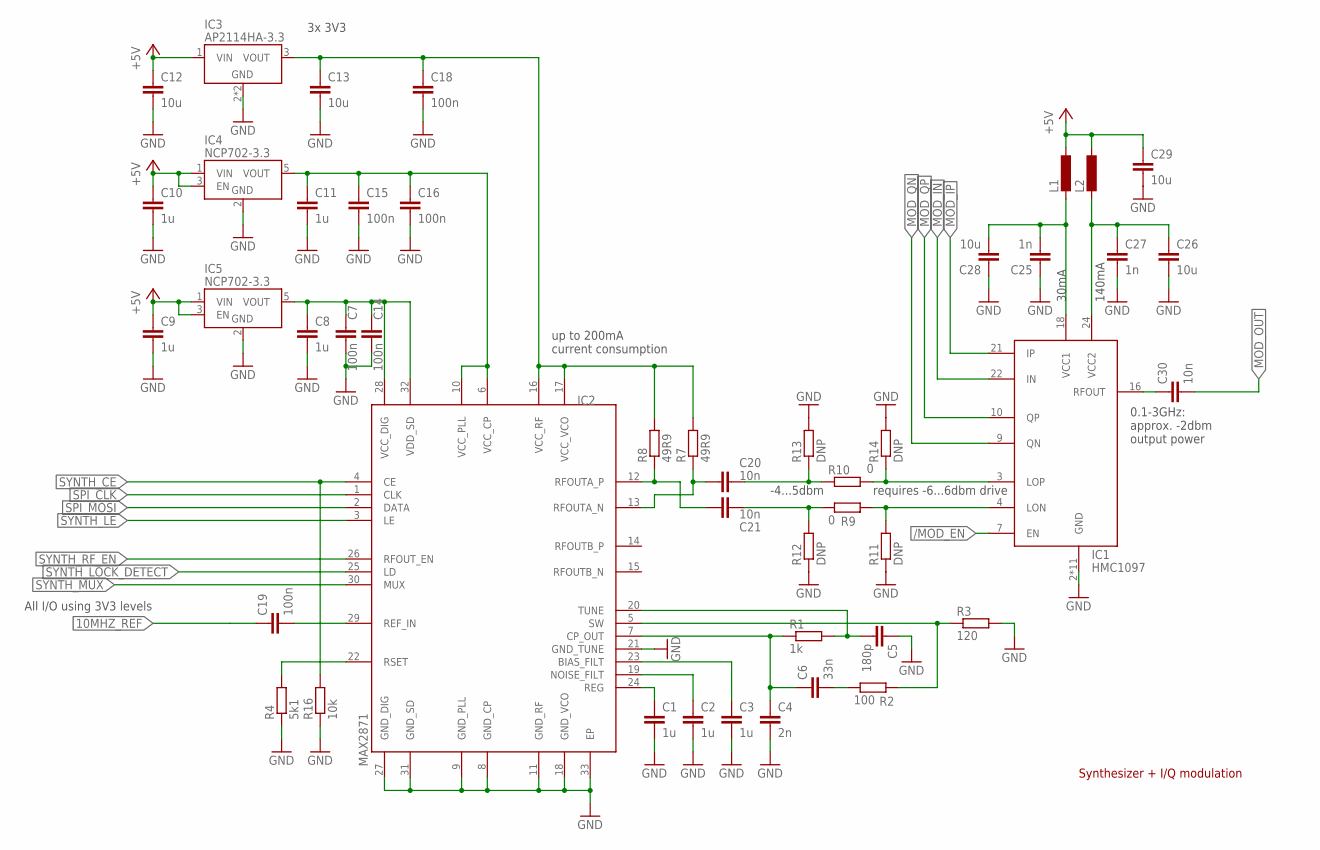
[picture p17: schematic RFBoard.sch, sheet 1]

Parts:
C1, C2, C3, C8, C9, C10, C11: 1u; C0603
C4: 2n; C0603
C5: 180p; C0603
C6: 33n; C0603
C7, C14, C15, C16, C18, C19: 100n; C0603
C12, C13, C26, C28, C29: 10u; C1206
C20, C21, C30: 10n; C0603
C25, C27: 1n; C0603
IC1: HMC1097; QFN50P400X400X100-25T280
IC2: MAX2871; QFN50P500X500X80-33T310
IC3: AP2114HA-3.3; SOT230P700X180-4
IC4, IC5: NCP702-3.3; SOT95P240X110-5
L1, L2: L-EUL2012C; L2012C
R1: 1k; R0603
R2: 100; R0603
R3: 120; R0603
R4: 5k1; R0603
R7, R8: 49R9; R0603
R9, R10: 0; R0603
R11, R12, R13, R14: DNP; R0603
R16: 10k; R0603

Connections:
10MHZ_REF: C19.1; also elsewhere on the board
+5V: C9.1, C10.1, C12.1, C29.1, IC3.1 (VIN), IC4.1 (VIN), IC4.3 (EN), IC5.1 (VIN), IC5.3 (EN), L1.1, L2.1; also elsewhere on the board
/MOD_EN: IC1.7 (EN); also elsewhere on the board
GND: C1.2, C2.2, C3.2, C4.2, C5.1, C7.2, C8.2, C9.2, C10.2, C11.2, C12.2, C13.2, C14.2, C15.2, C16.2, C18.2, C25.1, C26.2, C27.2, C28.1, C29.2, IC1.2 (GND), IC1.5 (GND), IC1.8 (GND), IC1.11 (GND), IC1.12 (GND), IC1.14 (GND), IC1.17 (GND), IC1.19 (GND), IC1.20 (GND), IC1.23 (GND), IC1.25 (GND), IC2.8 (GND_CP), IC2.9 (GND_PLL), IC2.11 (GND_RF), IC2.18 (GND_VCO), IC2.21 (GND_TUNE), IC2.27 (GND_DIG), IC2.31 (GND_SD), IC2.33 (EP), IC3.2 (GND), IC3.4 (GND), IC4.2 (GND), IC5.2 (GND), R3.2, R4.1, R11.1, R12.1, R13.2, R14.2, R16.1; also elsewhere on the board
MOD_IN: IC1.22 (IN); also elsewhere on the board
MOD_IP: IC1.21 (IP); also elsewhere on the board
MOD_OUT: C30.2; also elsewhere on the board
MOD_QN: IC1.9 (QN); also elsewhere on the board
MOD_QP: IC1.10 (QP); also elsewhere on the board
unnamed: C5.2, IC2.20 (TUNE), R1.2
unnamed: C4.1, C6.1, IC2.7 (CP_OUT), R1.1
unnamed: C1.1, IC2.24 (REG)
unnamed: C2.1, IC2.19 (NOISE_FILT)
unnamed: C3.1, IC2.23 (BIAS_FILT)
unnamed: C6.2, R2.1
unnamed: IC2.5 (SW), R2.2, R3.1
unnamed: IC2.22 (RSET), R4.2
unnamed: C19.2, IC2.29 (REF_IN)
unnamed: C13.1, C18.1, IC2.16 (VCC_RF), IC2.17 (VCC_VCO), IC3.3 (VOUT), R7.2, R8.2
unnamed: C11.1, C15.1, C16.1, IC2.6 (VCC_CP), IC2.10 (VCC_PLL), IC4.5 (VOUT)
unnamed: C20.1, IC2.13 (RFOUTA_N), R7.1
unnamed: C7.1, C8.1, C14.1, IC2.28 (VCC_DIG), IC2.32 (VDD_SD), IC5.5 (VOUT)
unnamed: C21.1, IC2.12 (RFOUTA_P), R8.1
unnamed: C20.2, R10.1, R13.1
unnamed: C21.2, R9.1, R12.2
unnamed: IC1.3 (LOP), R10.2, R14.1
unnamed: IC1.4 (LON), R9.2, R11.2
unnamed: C30.1, IC1.16 (RFOUT)
SPI_CLK: IC2.1 (CLK); also elsewhere on the board
SPI_MOSI: IC2.2 (DATA); also elsewhere on the board
SYNTH_CE: IC2.4 (CE), R16.2; also elsewhere on the board
SYNTH_LE: IC2.3 (LE); also elsewhere on the board
SYNTH_LOCK_DETECT: IC2.25 (LD); also elsewhere on the board
SYNTH_MUX: IC2.30 (MUX); also elsewhere on the board
SYNTH_RF_EN: IC2.26 (RFOUT_EN); also elsewhere on the board
VDD: C25.2, C28.2, IC1.18 (VCC1), L1.2
VDD1: C26.1, C27.1, IC1.24 (VCC2), L2.2

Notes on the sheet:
up to 200mA current consumption
All I/O using 3V3 levels
30mA
140mA
-4...5dbm
requires -6...6dbm drive
0.1-3GHz: approx. -2dbm output power
3x 3V3
Synthesizer + I/Q modulation

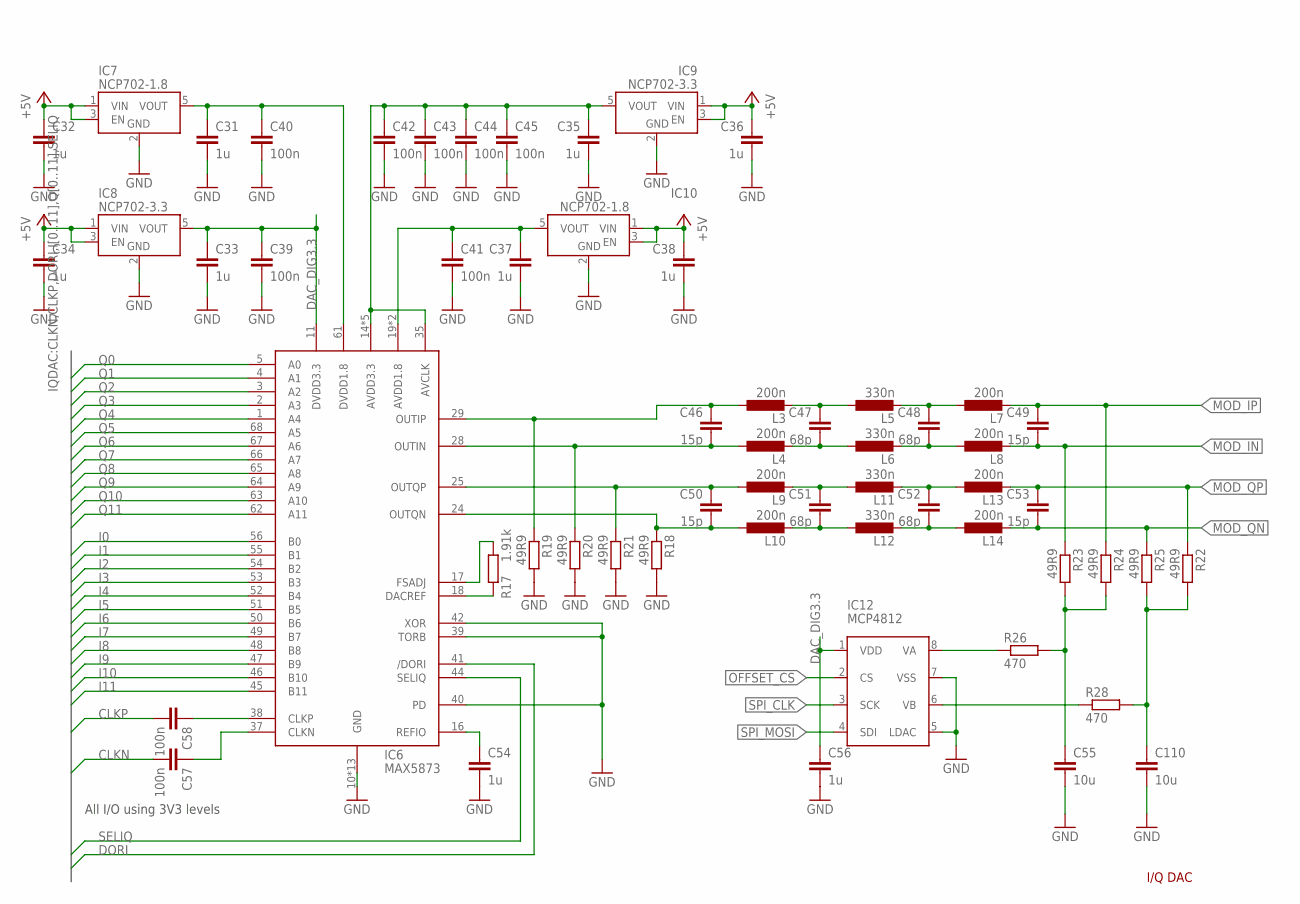
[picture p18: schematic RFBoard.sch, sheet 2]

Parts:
C31, C32, C33, C34, C35, C36, C37, C38, C54, C56: 1u; C0603
C39, C40, C41, C42, C43, C44, C45, C57, C58: 100n; C0603
C46, C49, C50, C53: 15p; C0603
C47, C48, C51, C52: 68p; C0603
C55, C110: 10u; C0603
IC6: MAX5873; QFN50P1000X1000X100-69T770
IC7, IC10: NCP702-1.8; SOT95P240X110-5
IC8, IC9: NCP702-3.3; SOT95P240X110-5
IC12: MCP4812; SO08
L3, L4, L7, L8, L9, L10, L13, L14: 200n; R0603
L5, L6, L11, L12: 330n; R0603
R17: 1.91k; R0603
R18, R19, R20, R21, R22, R23, R24, R25: 49R9; R0603
R26, R28: 470; R0603

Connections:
+5V: C32.1, C34.1, C36.1, C38.1, IC7.1 (VIN), IC7.3 (EN), IC8.1 (VIN), IC8.3 (EN), IC9.1 (VIN), IC9.3 (EN), IC10.1 (VIN), IC10.3 (EN); also elsewhere on the board
CLKN: C57.2; also elsewhere on the board
CLKP: C58.2; also elsewhere on the board
DAC_DIG3.3: C33.1, C39.1, C56.1, IC6.11 (DVDD3.3), IC8.5 (VOUT), IC12.1 (VDD)
DORI: IC6.41 (/DORI); also elsewhere on the board
GND: C31.2, C32.2, C33.2, C34.2, C35.2, C36.2, C37.2, C38.2, C39.2, C40.2, C41.2, C42.2, C43.2, C44.2, C45.2, C54.2, C55.2, C56.2, C110.2, IC6.10 (GND), IC6.12 (GND), IC6.13 (GND), IC6.15 (GND), IC6.20 (GND), IC6.23 (GND), IC6.26 (GND), IC6.27 (GND), IC6.30 (GND), IC6.33 (GND), IC6.36 (GND), IC6.39 (TORB), IC6.40 (PD), IC6.42 (XOR), IC6.43 (GND), IC6.69 (GND), IC7.2 (GND), IC8.2 (GND), IC9.2 (GND), IC10.2 (GND), IC12.5 (LDAC), IC12.7 (VSS), R18.2, R19.2, R20.2, R21.2; also elsewhere on the board
I0: IC6.56 (B0); also elsewhere on the board
I1: IC6.55 (B1); also elsewhere on the board
I2: IC6.54 (B2); also elsewhere on the board
I3: IC6.53 (B3); also elsewhere on the board
I4: IC6.52 (B4); also elsewhere on the board
I5: IC6.51 (B5); also elsewhere on the board
I6: IC6.50 (B6); also elsewhere on the board
I7: IC6.49 (B7); also elsewhere on the board
I8: IC6.48 (B8); also elsewhere on the board
I9: IC6.47 (B9); also elsewhere on the board
I10: IC6.46 (B10); also elsewhere on the board
I11: IC6.45 (B11); also elsewhere on the board
MOD_IN: C49.2, L8.2, R23.1; also elsewhere on the board
MOD_IP: C49.1, L7.2, R24.1; also elsewhere on the board
MOD_QN: C53.2, L14.2, R25.1; also elsewhere on the board
MOD_QP: C53.1, L13.2, R22.1; also elsewhere on the board
unnamed: C31.1, C40.1, IC6.61 (DVDD1.8), IC7.5 (VOUT)
unnamed: C58.1, IC6.38 (CLKP)
unnamed: C35.1, C42.1, C43.1, C44.1, C45.1, IC6.14 (AVDD3.3), IC6.21 (AVDD3.3), IC6.22 (AVDD3.3), IC6.31 (AVDD3.3), IC6.32 (AVDD3.3), IC6.35 (AVCLK), IC9.5 (VOUT)
unnamed: C37.1, C41.1, IC6.19 (AVDD1.8), IC6.34 (AVDD1.8), IC10.5 (VOUT)
unnamed: IC6.18 (DACREF), R17.2
unnamed: IC6.17 (FSADJ), R17.1
unnamed: C55.1, R23.2, R24.2, R26.2
unnamed: C110.1, R22.2, R25.2, R28.2
unnamed: C46.2, IC6.28 (OUTIN), L4.1, R20.1
unnamed: C46.1, IC6.29 (OUTIP), L3.1, R19.1
unnamed: C47.2, L4.2, L6.1
unnamed: C48.2, L6.2, L8.1
unnamed: C47.1, L3.2, L5.1
unnamed: C48.1, L5.2, L7.1
unnamed: C54.1, IC6.16 (REFIO)
unnamed: IC12.8 (VA), R26.1
unnamed: C50.2, IC6.24 (OUTQN), L10.1, R18.1
unnamed: C50.1, IC6.25 (OUTQP), L9.1, R21.1
unnamed: C51.2, L10.2, L12.1
unnamed: C52.2, L12.2, L14.1
unnamed: C51.1, L9.2, L11.1
unnamed: C52.1, L11.2, L13.1
unnamed: C57.1, IC6.37 (CLKN)
unnamed: IC12.6 (VB), R28.1
OFFSET_CS: IC12.2 (CS); also elsewhere on the board
Q0: IC6.5 (A0); also elsewhere on the board
Q1: IC6.4 (A1); also elsewhere on the board
Q2: IC6.3 (A2); also elsewhere on the board
Q3: IC6.2 (A3); also elsewhere on the board
Q4: IC6.1 (A4); also elsewhere on the board
Q5: IC6.68 (A5); also elsewhere on the board
Q6: IC6.67 (A6); also elsewhere on the board
Q7: IC6.66 (A7); also elsewhere on the board
Q8: IC6.65 (A8); also elsewhere on the board
Q9: IC6.64 (A9); also elsewhere on the board
Q10: IC6.63 (A10); also elsewhere on the board
Q11: IC6.62 (A11); also elsewhere on the board
SELIQ: IC6.44 (SELIQ); also elsewhere on the board
SPI_CLK: IC12.3 (SCK); also elsewhere on the board
SPI_MOSI: IC12.4 (SDI); also elsewhere on the board

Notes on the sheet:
I/Q DAC
All I/O using 3V3 levels

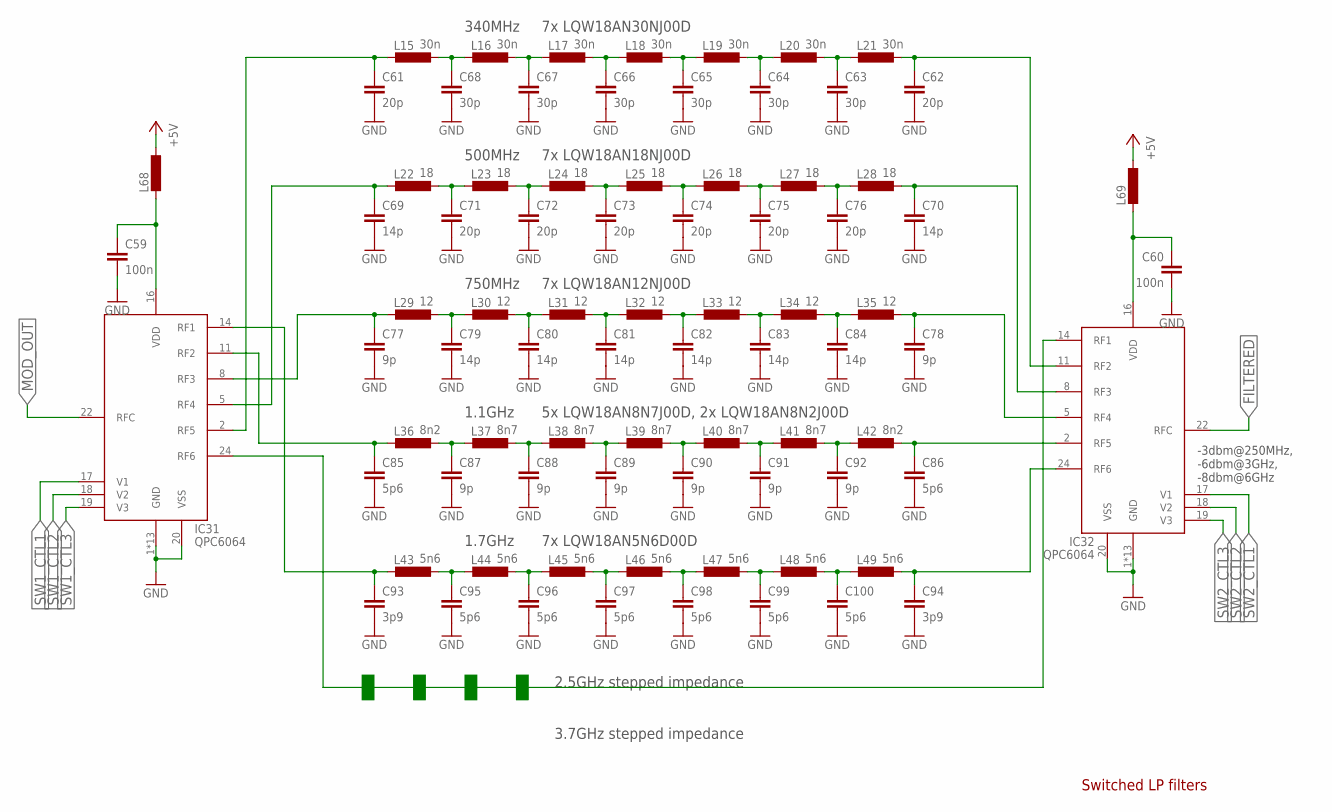
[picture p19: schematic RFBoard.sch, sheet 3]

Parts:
C59, C60: 100n; C0603
C61, C62, C71, C72, C73, C74, C75, C76: 20p; C0603
C63, C64, C65, C66, C67, C68: 30p; C0603
C69, C70, C79, C80, C81, C82, C83, C84: 14p; C0603
C77, C78, C87, C88, C89, C90, C91, C92: 9p; C0603
C85, C86, C95, C96, C97, C98, C99, C100: 5p6; C0603
C93, C94: 3p9; C0603
IC31, IC32: QPC6064; QFN50P400X400X75-25T270
L15, L16, L17, L18, L19, L20, L21: 30n; R0603
L22, L23, L24, L25, L26, L27, L28: 18; R0603
L29, L30, L31, L32, L33, L34, L35: 12; R0603
L36, L42: 8n2; R0603
L37, L38, L39, L40, L41: 8n7; R0603
L43, L44, L45, L46, L47, L48, L49: 5n6; R0603
L68, L69: L-EUL2012C; L2012C

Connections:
+5V: L68.1, L69.1; also elsewhere on the board
FILTERED: IC32.22 (RFC); also elsewhere on the board
GND: C59.2, C60.2, C61.2, C62.2, C63.2, C64.2, C65.2, C66.2, C67.2, C68.2, C69.2, C70.2, C71.2, C72.2, C73.2, C74.2, C75.2, C76.2, C77.2, C78.2, C79.2, C80.2, C81.2, C82.2, C83.2, C84.2, C85.2, C86.2, C87.2, C88.2, C89.2, C90.2, C91.2, C92.2, C93.2, C94.2, C95.2, C96.2, C97.2, C98.2, C99.2, C100.2, IC31.1 (GND), IC31.3 (GND), IC31.4 (GND), IC31.6 (GND), IC31.7 (GND), IC31.9 (GND), IC31.10 (GND), IC31.12 (GND), IC31.13 (GND), IC31.15 (GND), IC31.20 (VSS), IC31.21 (GND), IC31.23 (GND), IC31.25 (GND), IC32.1 (GND), IC32.3 (GND), IC32.4 (GND), IC32.6 (GND), IC32.7 (GND), IC32.9 (GND), IC32.10 (GND), IC32.12 (GND), IC32.13 (GND), IC32.15 (GND), IC32.20 (VSS), IC32.21 (GND), IC32.23 (GND), IC32.25 (GND); also elsewhere on the board
MOD_OUT: IC31.22 (RFC); also elsewhere on the board
unnamed: C68.1, L15.1, L16.2
unnamed: C67.1, L16.1, L17.2
unnamed: C66.1, L17.1, L18.2
unnamed: C65.1, L18.1, L19.2
unnamed: C64.1, L19.1, L20.2
unnamed: C63.1, L20.1, L21.2
unnamed: C61.1, IC31.2 (RF5), L15.2
unnamed: C62.1, IC32.11 (RF2), L21.1
unnamed: C71.1, L22.1, L23.2
unnamed: C72.1, L23.1, L24.2
unnamed: C73.1, L24.1, L25.2
unnamed: C74.1, L25.1, L26.2
unnamed: C75.1, L26.1, L27.2
unnamed: C76.1, L27.1, L28.2
unnamed: C69.1, IC31.5 (RF4), L22.2
unnamed: C79.1, L29.1, L30.2
unnamed: C80.1, L30.1, L31.2
unnamed: C81.1, L31.1, L32.2
unnamed: C82.1, L32.1, L33.2
unnamed: C83.1, L33.1, L34.2
unnamed: C84.1, L34.1, L35.2
unnamed: C78.1, IC32.5 (RF4), L35.1
unnamed: C87.1, L36.1, L37.2
unnamed: C88.1, L37.1, L38.2
unnamed: C89.1, L38.1, L39.2
unnamed: C90.1, L39.1, L40.2
unnamed: C91.1, L40.1, L41.2
unnamed: C92.1, L41.1, L42.2
unnamed: C85.1, IC31.11 (RF2), L36.2
unnamed: C86.1, IC32.2 (RF5), L42.1
unnamed: C95.1, L43.1, L44.2
unnamed: C96.1, L44.1, L45.2
unnamed: C97.1, L45.1, L46.2
unnamed: C98.1, L46.1, L47.2
unnamed: C99.1, L47.1, L48.2
unnamed: C100.1, L48.1, L49.2
unnamed: C93.1, IC31.14 (RF1), L43.2
unnamed: C94.1, IC32.24 (RF6), L49.1
unnamed: C77.1, IC31.8 (RF3), L29.2
unnamed: C70.1, IC32.8 (RF3), L28.1
STEPPED25: IC31.24 (RF6), IC32.14 (RF1)
SW1_CTL1: IC31.17 (V1); also elsewhere on the board
SW1_CTL2: IC31.18 (V2); also elsewhere on the board
SW1_CTL3: IC31.19 (V3); also elsewhere on the board
SW2_CTL1: IC32.17 (V1); also elsewhere on the board
SW2_CTL2: IC32.18 (V2); also elsewhere on the board
SW2_CTL3: IC32.19 (V3); also elsewhere on the board
SWITCHES_VCC: C60.1, IC32.16 (VDD), L69.2
VDD2: C59.1, IC31.16 (VDD), L68.2

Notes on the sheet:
Switched LP filters
7x LQW18AN30NJ00D
340MHz
7x LQW18AN18NJ00D
500MHz
7x LQW18AN12NJ00D
750MHz
5x LQW18AN8N7J00D, 2x LQW18AN8N2J00D
1.1GHz
7x LQW18AN5N6D00D
1.7GHz
2.5GHz stepped impedance
3.7GHz stepped impedance
-3dbm@250MHz, -6dbm@3GHz, -8dbm@6GHz

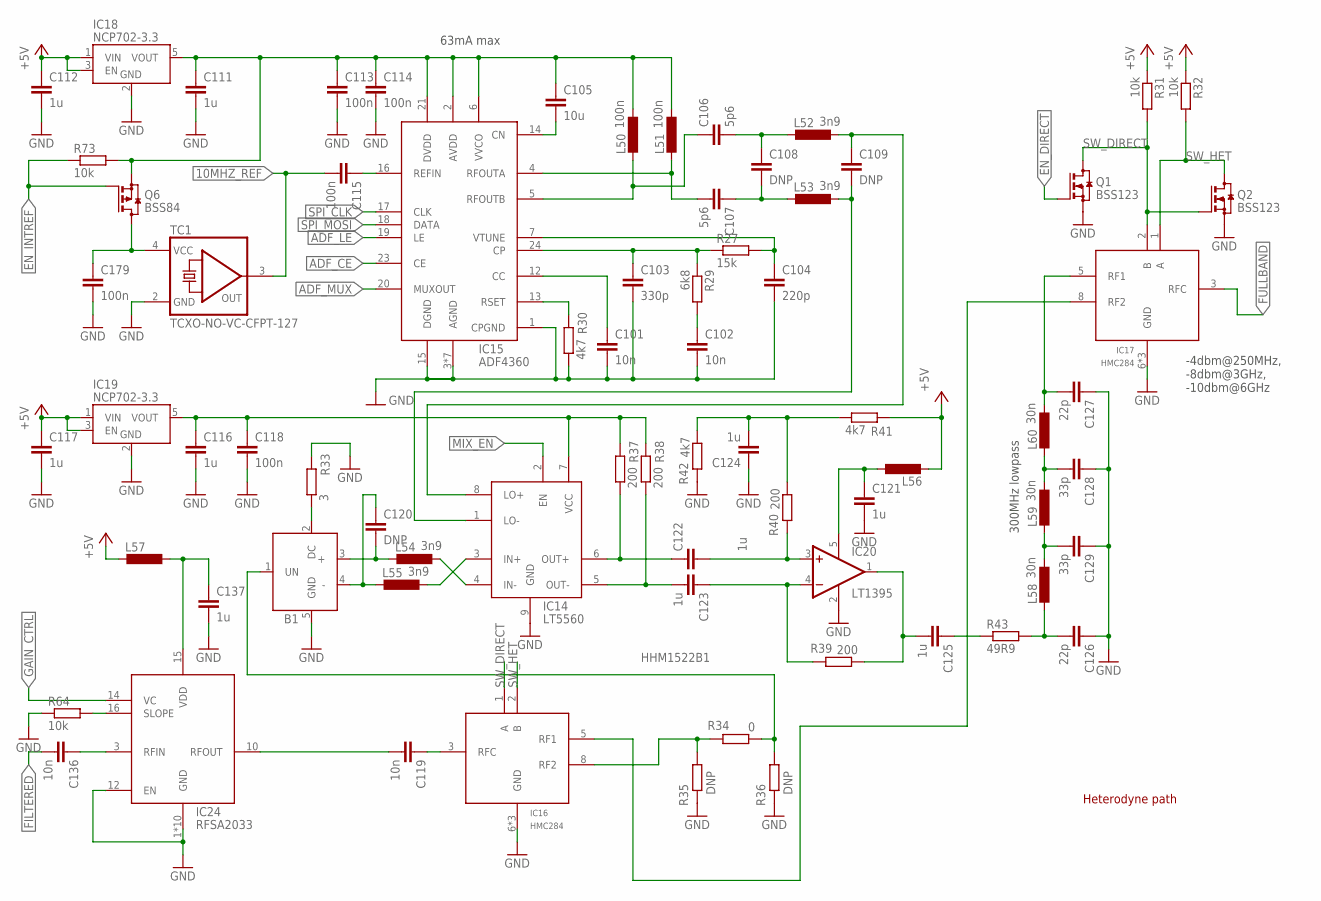
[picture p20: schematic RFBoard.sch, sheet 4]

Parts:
B1: HHM1522B1; INDCAF65P200X125X95-6
C101, C102, C119, C136: 10n; C0603
C103: 330p; C0603
C104: 220p; C0603
C105: 10u; C0603
C106, C107: 5p6; C0603
C108, C109, C120: DNP; C0603
C111, C112, C116, C117, C121, C122, C123, C124, C125, C137: 1u; C0603
C113, C114, C115, C118, C179: 100n; C0603
C126, C127: 22p; C0603
C128, C129: 33p; C0603
IC14: LT5560; SON50P300X300X80-9T165X238
IC15: ADF4360; QFN50P400X400X80-25T230
IC16, IC17: HMC284; MSOP08
IC18, IC19: NCP702-3.3; SOT95P240X110-5
IC20: LT1395; SOT23-5
IC24: RFSA2033; QFN50P300X300X85-17T170
L50, L51: 100n; R0603
L52, L53, L54, L55: 3n9; R0603
L56, L57: L-EUL2012C; L2012C
L58, L59, L60: 30n; R0603
Q1, Q2: BSS123; SOT23
Q6: BSS84; SOT23
R27: 15k; R0603
R29: 6k8; R0603
R30, R41, R42: 4k7; R0603
R31, R32, R64, R73: 10k; R0603
R33: 3; R0603
R34: 0; R0603
R35, R36: DNP; R0603
R37, R38, R39, R40: 200; R0603
R43: 49R9; R0603
TC1: TCXO-NO-VC-CFPT-127; 5.0X3.2-TCXO

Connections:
10MHZ_REF: C115.2, TC1.3 (OUT); also elsewhere on the board
+5V: C112.1, C117.1, IC18.1 (VIN), IC18.3 (EN), IC19.1 (VIN), IC19.3 (EN), L56.2, L57.2, R31.1, R32.1, R41.2; also elsewhere on the board
ADF_CE: IC15.23 (CE); also elsewhere on the board
ADF_LE: IC15.19 (LE); also elsewhere on the board
ADF_MUX: IC15.20 (MUXOUT); also elsewhere on the board
DAC_DIG3.2: C116.1, C118.1, IC14.7 (VCC), IC19.5 (VOUT), R37.2, R38.2
EN_DIRECT: Q1.1 (G); also elsewhere on the board
EN_INTREF: Q6.1 (G), R73.1; also elsewhere on the board
FILTERED: C136.2; also elsewhere on the board
FULLBAND: IC17.3 (RFC); also elsewhere on the board
GAIN_CTRL: IC24.14 (VC); also elsewhere on the board
GND: B1.5 (GND), C101.2, C102.2, C103.2, C104.2, C111.2, C112.2, C113.2, C114.2, C116.2, C117.2, C118.2, C121.2, C124.1, C126.1, C127.1, C128.1, C129.1, C137.2, C179.2, IC14.9 (GND), IC15.1 (CPGND), IC15.3 (AGND), IC15.8 (AGND), IC15.9 (AGND), IC15.10 (AGND), IC15.11 (AGND), IC15.15 (DGND), IC15.22 (AGND), IC15.25 (AGND), IC16.6 (GND), IC16.7 (GND), IC16.9 (GND), IC17.6 (GND), IC17.7 (GND), IC17.9 (GND), IC18.2 (GND), IC19.2 (GND), IC20.2 (V-), IC24.1 (GND), IC24.2 (GND), IC24.4 (GND), IC24.5 (GND), IC24.6 (GND), IC24.7 (GND), IC24.8 (GND), IC24.9 (GND), IC24.11 (GND), IC24.12 (EN), IC24.17 (GND), Q1.2 (S), Q2.2 (S), R30.1, R33.2, R35.2, R36.2, R42.2, R64.1, TC1.2 (GND); also elsewhere on the board
MIX_EN: IC14.2 (EN); also elsewhere on the board
unnamed: IC14.3 (IN+), L55.1
unnamed: IC14.4 (IN-), L54.1
unnamed: IC15.13 (RSET), R30.2
unnamed: C101.1, IC15.12 (CC)
unnamed: C102.1, R29.2
unnamed: C103.1, IC15.24 (CP), R27.1, R29.1
unnamed: C104.1, IC15.7 (VTUNE), R27.2
unnamed: C115.1, IC15.16 (REFIN)
unnamed: C105.2, IC15.14 (CN)
unnamed: C106.1, IC15.5 (RFOUTB), L50.2
unnamed: C107.2, IC15.4 (RFOUTA), L51.2
unnamed: C106.2, C108.1, L52.2
unnamed: C107.1, C108.2, L53.2
unnamed: C109.1, IC14.8 (LO+), L52.1
unnamed: C109.2, IC14.1 (LO-), L53.1
unnamed: C119.1, IC16.3 (RFC)
unnamed: B1.3 (+), C120.2, L54.2
unnamed: B1.4 (-), C120.1, L55.2
unnamed: IC16.5 (RF1), IC17.8 (RF2)
unnamed: IC16.8 (RF2), R34.2, R35.1
unnamed: B1.2 (DC), R33.1
unnamed: B1.1 (UN), R34.1, R36.1
unnamed: C121.1, IC20.5 (V+), L56.1
unnamed: C122.1, IC14.6 (OUT+), R37.1
unnamed: C123.2, IC14.5 (OUT-), R38.1
unnamed: C125.2, IC20.1 (OUT), R39.1
unnamed: C123.1, IC20.4 (-IN), R39.2
unnamed: C122.2, IC20.3 (+IN), R40.2
unnamed: C124.2, R40.1, R41.1, R42.1
unnamed: C125.1, R43.1
unnamed: C127.2, IC17.5 (RF1), L60.1
unnamed: C126.2, L58.2, R43.2
unnamed: C129.2, L58.1, L59.2
unnamed: C128.2, L59.1, L60.2
unnamed: C119.2, IC24.10 (RFOUT)
unnamed: C136.1, IC24.3 (RFIN)
unnamed: C137.1, IC24.15 (VDD), L57.1
unnamed: IC24.16 (SLOPE), R64.2
unnamed: C179.1, Q6.3 (D), TC1.4 (VCC)
PLL_DIG3: C105.1, C111.1, C113.1, C114.1, IC15.2 (AVDD), IC15.6 (VVCO), IC15.21 (DVDD), IC18.5 (VOUT), L50.1, L51.1, Q6.2 (S), R73.2
SPI_CLK: IC15.17 (CLK); also elsewhere on the board
SPI_MOSI: IC15.18 (DATA); also elsewhere on the board
SW_DIRECT: IC16.1 (A), IC17.2 (B), Q1.3 (D), Q2.1 (G), R31.2
SW_HET: IC16.2 (B), IC17.1 (A), Q2.3 (D), R32.2

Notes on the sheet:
Heterodyne path
-4dbm@250MHz, -8dbm@3GHz, -10dbm@6GHz
300MHz lowpass
63mA max

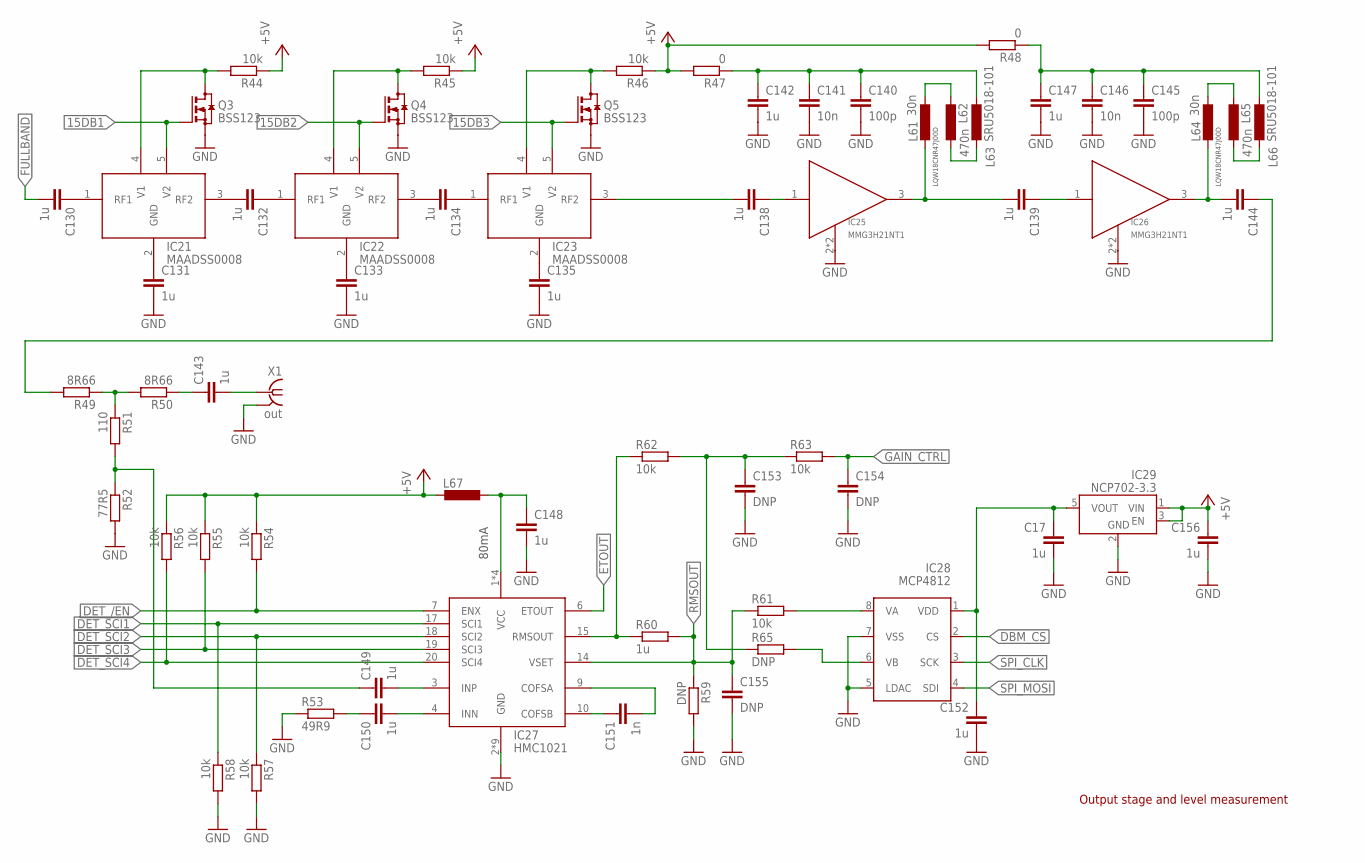
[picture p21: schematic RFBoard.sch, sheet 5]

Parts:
C17, C130, C131, C132, C133, C134, C135, C138, C139, C142, C143, C144, C147, C148, C149, C150, C152, C156: 1u; C0603
C140, C145: 100p; C0603
C141, C146: 10n; C0603
C151: 1n; C0603
C153, C154, C155: DNP; C0603
IC21, IC22, IC23: MAADSS0008; SOT95P280X110-5
IC25, IC26: MMG3H21NT1; SOT89
IC27: HMC1021; QFN50P400X400X100-25T270
IC28: MCP4812; SO08
IC29: NCP702-3.3; SOT95P240X110-5
L61, L64: 30n; R0603
L62, L65: 470n; R0603
L63, L66: SRU5018-101; SMD5018
L67: L-EUL2012C; L2012C
Q3, Q4, Q5: BSS123; SOT23
R44, R45, R46, R54, R55, R56, R57, R58, R61, R62, R63: 10k; R0603
R47, R48: 0; R0603
R49, R50: 8R66; R0603
R51: 110; R0603
R52: 77R5; R0603
R53: 49R9; R0603
R59, R65: DNP; R0603
R60: 1u; R0603
X1: out; J502-ND-142-0711-821/826

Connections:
15DB1: IC21.5 (V2), Q3.1 (G); also elsewhere on the board
15DB2: IC22.5 (V2), Q4.1 (G); also elsewhere on the board
15DB3: IC23.5 (V2), Q5.1 (G); also elsewhere on the board
+5V: C156.1, IC29.1 (VIN), IC29.3 (EN), L67.2, R44.1, R45.1, R46.1, R47.2, R48.2, R54.1, R55.1, R56.1; also elsewhere on the board
DBM_CS: IC28.2 (CS); also elsewhere on the board
DET_/EN: IC27.7 (ENX), R54.2; also elsewhere on the board
DET_SCI1: IC27.17 (SCI1), R58.1; also elsewhere on the board
DET_SCI2: IC27.18 (SCI2), R57.1; also elsewhere on the board
DET_SCI3: IC27.19 (SCI3), R55.2; also elsewhere on the board
DET_SCI4: IC27.20 (SCI4), R56.2; also elsewhere on the board
ETOUT: IC27.6 (ETOUT); also elsewhere on the board
FULLBAND: C130.2; also elsewhere on the board
GAIN_CTRL: C154.1, R63.2; also elsewhere on the board
GND: C17.2, C131.2, C133.2, C135.2, C140.2, C141.2, C142.2, C145.2, C146.2, C147.2, C148.2, C152.2, C153.2, C154.2, C155.2, C156.2, IC25.2 (GND), IC25.2@1 (GND), IC26.2 (GND), IC26.2@1 (GND), IC27.2 (GND), IC27.5 (GND), IC27.8 (GND), IC27.11 (GND), IC27.12 (GND), IC27.13 (GND), IC27.22 (GND), IC27.24 (GND), IC27.25 (GND), IC28.5 (LDAC), IC28.7 (VSS), IC29.2 (GND), Q3.2 (S), Q4.2 (S), Q5.2 (S), R52.2, R53.1, R57.2, R58.2, R59.2, X1.G@1 (2), X1.G@2 (2), X1.G@3 (2), X1.G@4 (2); also elsewhere on the board
unnamed: IC28.8 (VA), R61.2
unnamed: IC28.6 (VB), R65.2
unnamed: C131.1, IC21.2 (GND)
unnamed: C130.1, IC21.1 (RF1)
unnamed: C132.1, IC22.1 (RF1)
unnamed: IC21.4 (V1), Q3.3 (D), R44.2
unnamed: C133.1, IC22.2 (GND)
unnamed: IC22.4 (V1), Q4.3 (D), R45.2
unnamed: C134.1, IC23.1 (RF1)
unnamed: C135.1, IC23.2 (GND)
unnamed: IC23.4 (V1), Q5.3 (D), R46.2
unnamed: C134.2, IC22.3 (RF2)
unnamed: C132.2, IC21.3 (RF2)
unnamed: C139.2, IC25.3 (OUT), L61.2
unnamed: C138.1, IC25.1 (IN)
unnamed: L61.1, L62.2
unnamed: L62.1, L63.P$3 (2)
unnamed: C144.2, IC26.3 (OUT), L64.2
unnamed: C140.1, C141.1, C142.1, L63.P$1 (1), R47.1
unnamed: C139.1, IC26.1 (IN)
unnamed: C145.1, C146.1, C147.1, L66.P$1 (1), R48.1
unnamed: L64.1, L65.2
unnamed: L65.1, L66.P$3 (2)
unnamed: C138.2, IC23.3 (RF2)
unnamed: C144.1, R49.2
unnamed: R49.1, R50.2, R51.1
unnamed: C143.1, R50.1
unnamed: C149.1, R51.2, R52.1
unnamed: C143.2, X1.1
unnamed: C148.1, IC27.1 (VCC), IC27.16 (VCC), IC27.21 (VCC), IC27.23 (VCC), L67.1
unnamed: C149.2, IC27.3 (INP)
unnamed: C150.2, IC27.4 (INN)
unnamed: C153.1, R62.2, R63.1, R65.1
unnamed: C150.1, R53.2
unnamed: C151.1, IC27.10 (COFSB)
unnamed: C151.2, IC27.9 (COFSA)
unnamed: IC27.15 (RMSOUT), R60.1, R62.1
RMSOUT: C155.1, IC27.14 (VSET), R59.1, R60.2, R61.1; also elsewhere on the board
SETDAC_VCC: C17.1, C152.1, IC28.1 (VDD), IC29.5 (VOUT)
SPI_CLK: IC28.3 (SCK); also elsewhere on the board
SPI_MOSI: IC28.4 (SDI); also elsewhere on the board

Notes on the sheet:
LQW18CNR47J00D
80mA
Output stage and level measurement

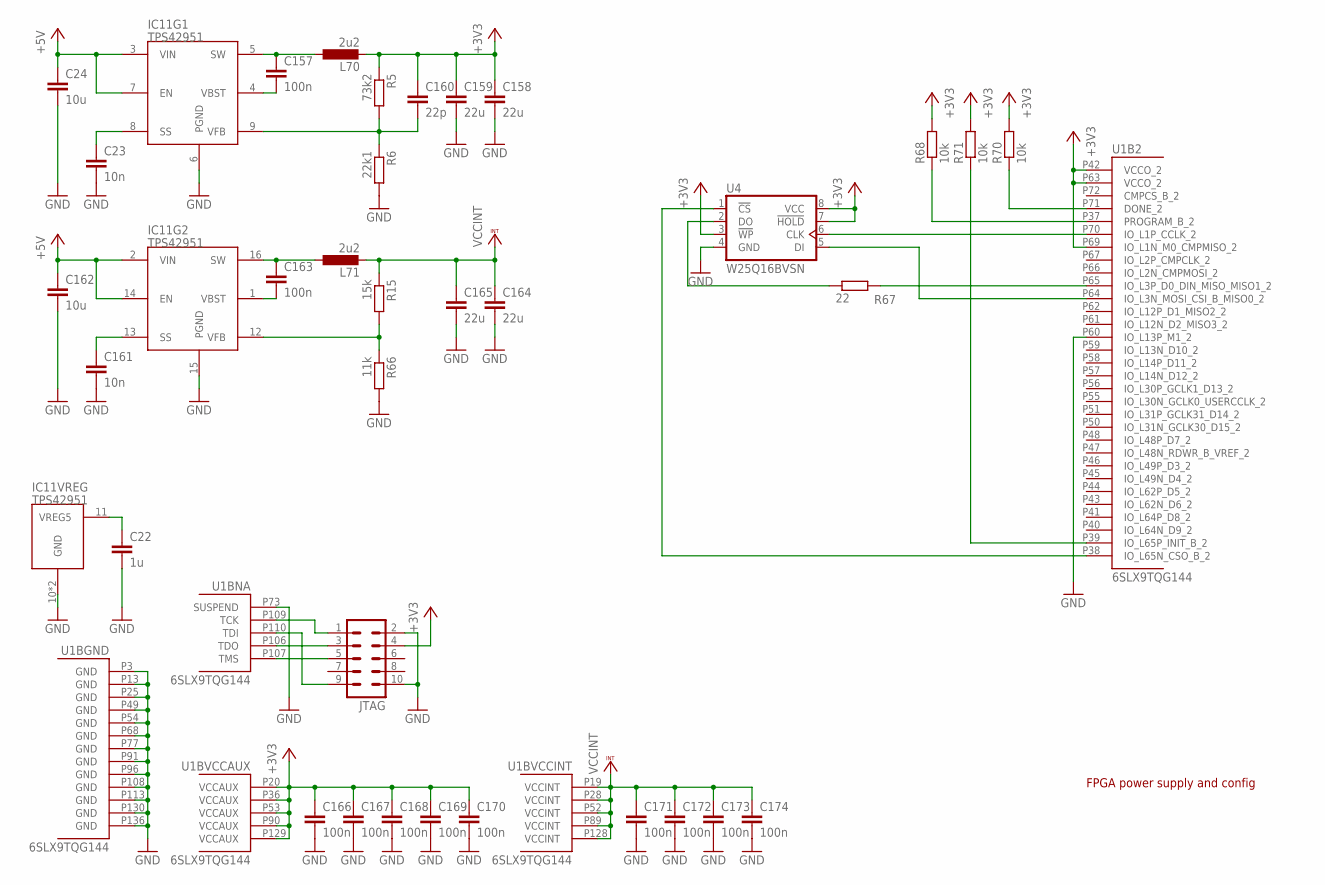
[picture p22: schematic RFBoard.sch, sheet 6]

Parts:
C22: 1u; C0603
C23, C161: 10n; C0603
C24, C162: 10u; C1206
C157, C163, C166, C167, C168, C169, C170, C171, C172, C173, C174: 100n; C0603
C158, C159, C164, C165: 22u; C1206
C160: 22p; C0603
IC11: TPS42951; QFN65P400X400X100-17T270
JTAG: ML10
L70, L71: 2u2; SRN5040
R5: 73k2; R0603
R6: 22k1; R0603
R15: 15k; R0603
R66: 11k; R0603
R67: 22; R0603
R68, R70, R71: 10k; R0603
U1: 6SLX9TQG144; TQ144
U4: W25Q16BVSN; SO08

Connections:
+3V3: C158.1, C159.1, C160.1, C166.1, C167.1, C168.1, C169.1, C170.1, JTAG.4, L70.P$2 (2), R5.1, R68.2, R70.2, R71.2, U1.P20 (VCCAUX), U1.P36 (VCCAUX), U1.P42 (VCCO_2), U1.P53 (VCCAUX), U1.P63 (VCCO_2), U1.P69 (IO_L1N_M0_CMPMISO_2), U1.P90 (VCCAUX), U1.P129 (VCCAUX), U4.3 (!WP!), U4.7 (!HOLD!), U4.8 (VCC); also elsewhere on the board
+5V: C24.1, C162.1, IC11.2 (VIN), IC11.3 (VIN), IC11.7 (EN), IC11.14 (EN); also elsewhere on the board
FLACH_MOSI: U1.P64 (IO_L3N_MOSI_CSI_B_MISO0_2), U4.5 (DI)
FLASH_CLK: U1.P70 (IO_L1P_CCLK_2), U4.6 (CLK)
FLASH_CS: U1.P38 (IO_L65N_CSO_B_2), U4.1 (!CS!)
FLASH_MISO: R67.1, U4.2 (DO)
GND: C22.2, C23.2, C24.2, C158.2, C159.2, C161.2, C162.2, C164.2, C165.2, C166.2, C167.2, C168.2, C169.2, C170.2, C171.2, C172.2, C173.2, C174.2, IC11.6 (PGND), IC11.10 (GND), IC11.15 (PGND), IC11.17 (GND), JTAG.2, JTAG.10, R6.2, R66.2, U1.P3 (GND), U1.P13 (GND), U1.P25 (GND), U1.P49 (GND), U1.P54 (GND), U1.P60 (IO_L13P_M1_2), U1.P68 (GND), U1.P73 (SUSPEND), U1.P77 (GND), U1.P91 (GND), U1.P96 (GND), U1.P108 (GND), U1.P113 (GND), U1.P130 (GND), U1.P136 (GND), U4.4 (GND); also elsewhere on the board
unnamed: JTAG.3, U1.P106 (TDO)
unnamed: JTAG.5, U1.P107 (TMS)
unnamed: JTAG.9, U1.P110 (TDI)
unnamed: JTAG.1, U1.P109 (TCK)
unnamed: C22.1, IC11.11 (VREG5)
unnamed: C23.1, IC11.8 (SS)
unnamed: C160.2, IC11.9 (VFB), R5.2, R6.1
unnamed: C161.1, IC11.13 (SS)
unnamed: C157.1, IC11.5 (SW), L70.P$1 (1)
unnamed: C157.2, IC11.4 (VBST)
unnamed: IC11.12 (VFB), R15.2, R66.1
unnamed: C163.1, IC11.16 (SW), L71.P$1 (1)
unnamed: C163.2, IC11.1 (VBST)
unnamed: R67.2, U1.P65 (IO_L3P_D0_DIN_MISO_MISO1_2)
unnamed: R70.1, U1.P71 (DONE_2)
unnamed: R68.1, U1.P37 (PROGRAM_B_2)
unnamed: R71.1, U1.P39 (IO_L65P_INIT_B_2)
VCCINT: C164.1, C165.1, C171.1, C172.1, C173.1, C174.1, L71.P$2 (2), R15.1, U1.P19 (VCCINT), U1.P28 (VCCINT), U1.P52 (VCCINT), U1.P89 (VCCINT), U1.P128 (VCCINT); also elsewhere on the board

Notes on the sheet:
FPGA power supply and config

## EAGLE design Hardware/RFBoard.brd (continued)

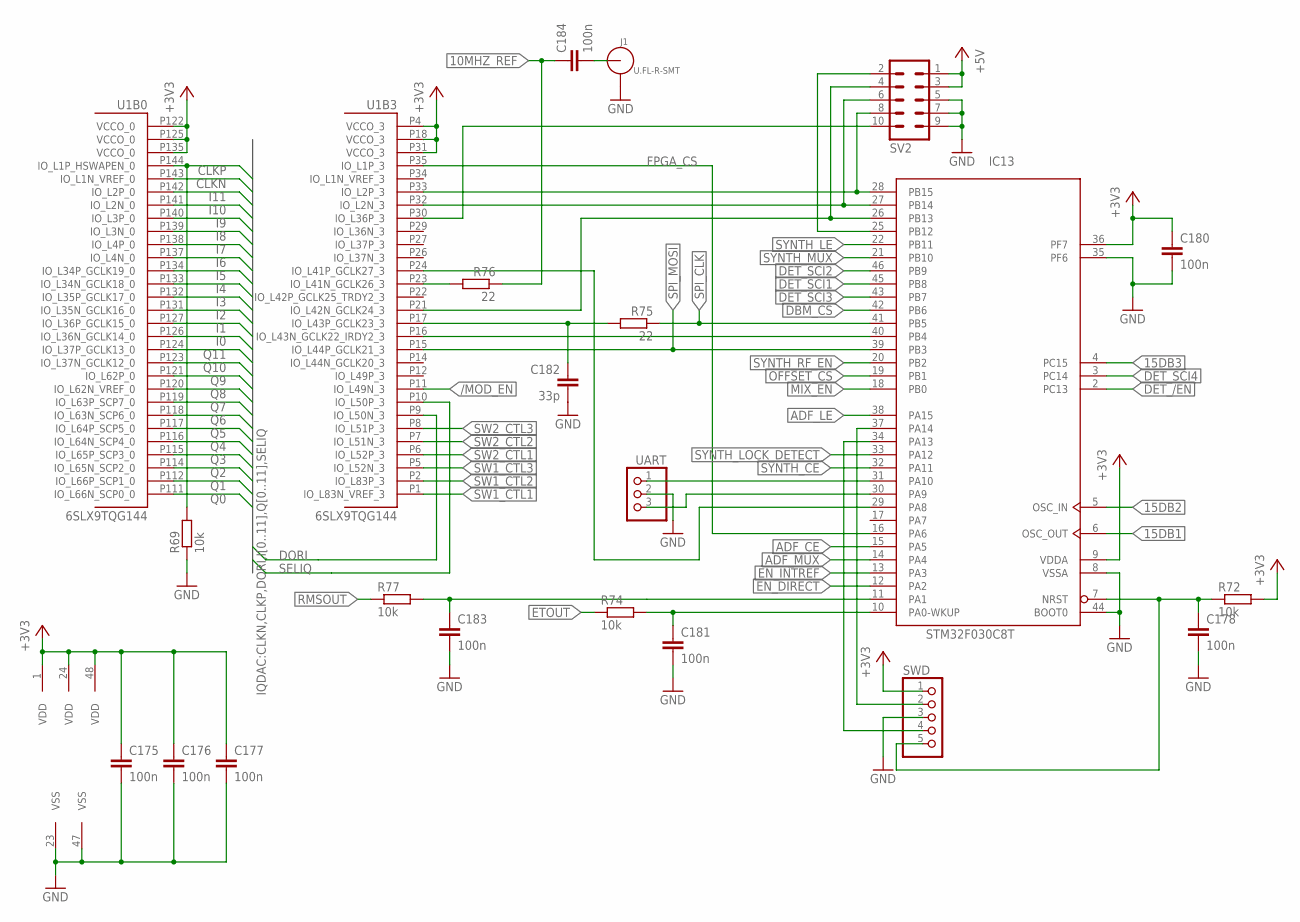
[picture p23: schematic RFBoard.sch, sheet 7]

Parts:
C175, C176, C177, C178, C180, C181, C183, C184: 100n; C0603
C182: 33p; C0603
IC13: STM32F030C8T; LQFP48
J1: U.FL-R-SMT; U.FL_SMT
R69, R72, R74, R77: 10k; R0603
R75, R76: 22; R0603
SV2: ML10
SWD: PINHD-1X5; 1X05
U1: 6SLX9TQG144; TQ144
UART: PINHD-1X3; 1X03

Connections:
10MHZ_REF: C184.1, R76.1; also elsewhere on the board
15DB1: IC13.6 (OSC_OUT); also elsewhere on the board
15DB2: IC13.5 (OSC_IN); also elsewhere on the board
15DB3: IC13.4 (PC15); also elsewhere on the board
+3V3: C175.1, C176.1, C177.1, C180.1, IC13.1 (VDD), IC13.9 (VDDA), IC13.24 (VDD), IC13.36 (PF7), IC13.48 (VDD), R72.2, SWD.1, U1.P4 (VCCO_3), U1.P18 (VCCO_3), U1.P31 (VCCO_3), U1.P122 (VCCO_0), U1.P125 (VCCO_0), U1.P135 (VCCO_0); also elsewhere on the board
+5V: SV2.1, SV2.3; also elsewhere on the board
/MOD_EN: U1.P11 (IO_L49N_3); also elsewhere on the board
ADF_CE: IC13.15 (PA5); also elsewhere on the board
ADF_LE: IC13.38 (PA15); also elsewhere on the board
ADF_MUX: IC13.14 (PA4); also elsewhere on the board
CLKN: U1.P143 (IO_L1N_VREF_0); also elsewhere on the board
CLKP: R69.2, U1.P144 (IO_L1P_HSWAPEN_0); also elsewhere on the board
CS: IC13.25 (PB12), SV2.2
CS_FPGA: SV2.10, U1.P30 (IO_L36P_3)
DBM_CS: IC13.42 (PB6); also elsewhere on the board
DET_/EN: IC13.2 (PC13); also elsewhere on the board
DET_SCI1: IC13.45 (PB8); also elsewhere on the board
DET_SCI2: IC13.46 (PB9); also elsewhere on the board
DET_SCI3: IC13.43 (PB7); also elsewhere on the board
DET_SCI4: IC13.3 (PC14); also elsewhere on the board
DORI: U1.P9 (IO_L50N_3); also elsewhere on the board
EN_DIRECT: IC13.12 (PA2); also elsewhere on the board
EN_INTREF: IC13.13 (PA3); also elsewhere on the board
ETOUT: R74.1; also elsewhere on the board
FPGA_CS: IC13.16 (PA6), U1.P35 (IO_L1P_3)
GND: C175.2, C176.2, C177.2, C178.2, C180.2, C181.2, C182.2, C183.2, IC13.8 (VSSA), IC13.23 (VSS), IC13.35 (PF6), IC13.44 (BOOT0), IC13.47 (VSS), J1.GND1, J1.GND2, R69.1, SV2.5, SV2.7, SV2.9, SWD.3, UART.2; also elsewhere on the board
I0: U1.P126 (IO_L36N_GCLK14_0); also elsewhere on the board
I1: U1.P127 (IO_L36P_GCLK15_0); also elsewhere on the board
I2: U1.P131 (IO_L35N_GCLK16_0); also elsewhere on the board
I3: U1.P132 (IO_L35P_GCLK17_0); also elsewhere on the board
I4: U1.P133 (IO_L34N_GCLK18_0); also elsewhere on the board
I5: U1.P134 (IO_L34P_GCLK19_0); also elsewhere on the board
I6: U1.P137 (IO_L4N_0); also elsewhere on the board
I7: U1.P138 (IO_L4P_0); also elsewhere on the board
I8: U1.P139 (IO_L3N_0); also elsewhere on the board
I9: U1.P140 (IO_L3P_0); also elsewhere on the board
I10: U1.P141 (IO_L2N_0); also elsewhere on the board
I11: U1.P142 (IO_L2P_0); also elsewhere on the board
MISO: IC13.27 (PB14), SV2.6, U1.P32 (IO_L2N_3)
MIX_EN: IC13.18 (PB0); also elsewhere on the board
MOSI: IC13.28 (PB15), SV2.8, U1.P33 (IO_L2P_3)
unnamed: C183.1, IC13.11 (PA1), R77.2
unnamed: C184.2, J1.SIG (ANT)
unnamed: IC13.29 (PA8), U1.P24 (IO_L41P_GCLK27_3)
unnamed: C181.1, IC13.10 (PA0-WKUP), R74.2
unnamed: C182.1, R75.2, U1.P17 (IO_L43P_GCLK23_3)
unnamed: IC13.40 (PB4), U1.P16 (IO_L43N_GCLK22_IRDY2_3)
unnamed: R76.2, U1.P23 (IO_L41N_GCLK26_3)
NRST: C178.1, IC13.7 (NRST), R72.1, SWD.5
OFFSET_CS: IC13.19 (PB1); also elsewhere on the board
Q0: U1.P111 (IO_L66N_SCP0_0); also elsewhere on the board
Q1: U1.P112 (IO_L66P_SCP1_0); also elsewhere on the board
Q2: U1.P114 (IO_L65N_SCP2_0); also elsewhere on the board
Q3: U1.P115 (IO_L65P_SCP3_0); also elsewhere on the board
Q4: U1.P116 (IO_L64N_SCP4_0); also elsewhere on the board
Q5: U1.P117 (IO_L64P_SCP5_0); also elsewhere on the board
Q6: U1.P118 (IO_L63N_SCP6_0); also elsewhere on the board
Q7: U1.P119 (IO_L63P_SCP7_0); also elsewhere on the board
Q8: U1.P120 (IO_L62N_VREF_0); also elsewhere on the board
Q9: U1.P121 (IO_L62P_0); also elsewhere on the board
Q10: U1.P123 (IO_L37N_GCLK12_0); also elsewhere on the board
Q11: U1.P124 (IO_L37P_GCLK13_0); also elsewhere on the board
RMSOUT: R77.1; also elsewhere on the board
RX: IC13.31 (PA10), UART.1
SCK: IC13.26 (PB13), SV2.4, U1.P21 (IO_L42N_GCLK24_3)
SELIQ: U1.P10 (IO_L50P_3); also elsewhere on the board
SPI_CLK: IC13.41 (PB5), R75.1; also elsewhere on the board
SPI_MOSI: IC13.39 (PB3), U1.P15 (IO_L44P_GCLK21_3); also elsewhere on the board
SW1_CTL1: U1.P1 (IO_L83N_VREF_3); also elsewhere on the board
SW1_CTL2: U1.P2 (IO_L83P_3); also elsewhere on the board
SW1_CTL3: U1.P5 (IO_L52N_3); also elsewhere on the board
SW2_CTL1: U1.P6 (IO_L52P_3); also elsewhere on the board
SW2_CTL2: U1.P7 (IO_L51N_3); also elsewhere on the board
SW2_CTL3: U1.P8 (IO_L51P_3); also elsewhere on the board
SWCLK: IC13.37 (PA14), SWD.2
SWDIO: IC13.34 (PA13), SWD.4
SYNTH_CE: IC13.32 (PA11); also elsewhere on the board
SYNTH_LE: IC13.22 (PB11); also elsewhere on the board
SYNTH_LOCK_DETECT: IC13.33 (PA12); also elsewhere on the board
SYNTH_MUX: IC13.21 (PB10); also elsewhere on the board
SYNTH_RF_EN: IC13.20 (PB2); also elsewhere on the board
TX: IC13.30 (PA9), UART.3

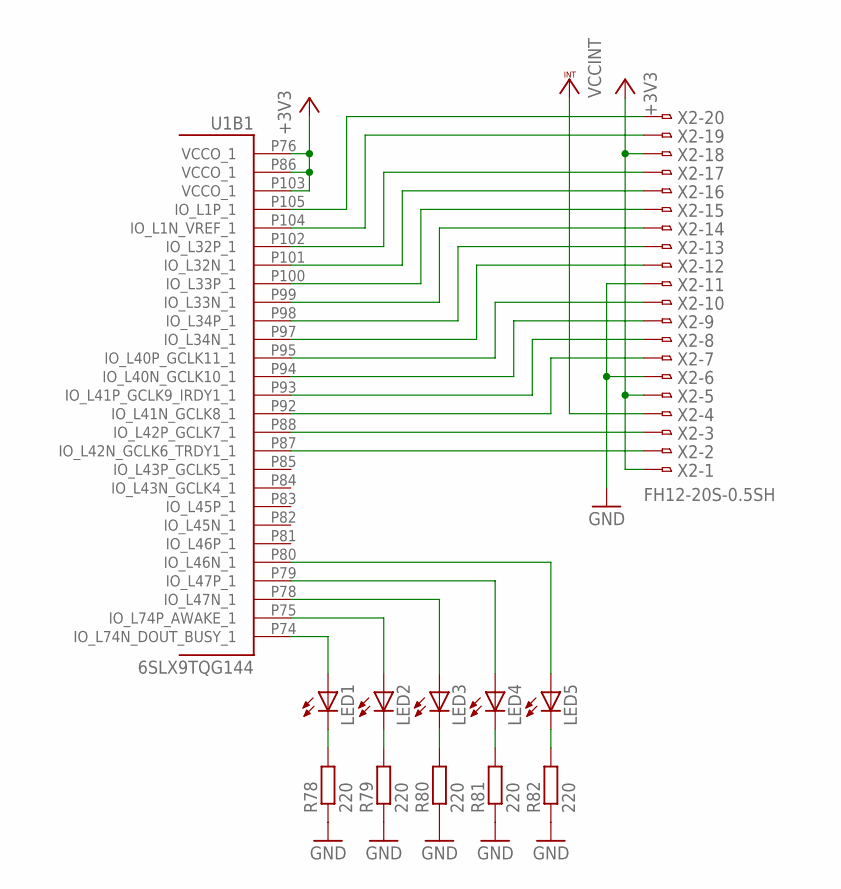
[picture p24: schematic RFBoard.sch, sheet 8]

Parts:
LED1, LED2, LED3, LED4, LED5: LEDCHIP-LED0603; CHIP-LED0603
R78, R79, R80, R81, R82: 220; R0603
U1: 6SLX9TQG144; TQ144
X2: FH12-20S-0.5SH

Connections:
+3V3: U1.P76 (VCCO_1), U1.P86 (VCCO_1), U1.P103 (VCCO_1), X2.1, X2.5, X2.18; also elsewhere on the board
GND: R78.1, R79.1, R80.1, R81.1, R82.1, X2.6, X2.11; also elsewhere on the board
unnamed: U1.P100 (IO_L33P_1), X2.15
unnamed: U1.P87 (IO_L42N_GCLK6_TRDY1_1), X2.2
unnamed: U1.P88 (IO_L42P_GCLK7_1), X2.3
unnamed: U1.P92 (IO_L41N_GCLK8_1), X2.7
unnamed: U1.P93 (IO_L41P_GCLK9_IRDY1_1), X2.8
unnamed: U1.P94 (IO_L40N_GCLK10_1), X2.9
unnamed: U1.P95 (IO_L40P_GCLK11_1), X2.10
unnamed: U1.P97 (IO_L34N_1), X2.12
unnamed: U1.P98 (IO_L34P_1), X2.13
unnamed: U1.P99 (IO_L33N_1), X2.14
unnamed: U1.P101 (IO_L32N_1), X2.16
unnamed: U1.P102 (IO_L32P_1), X2.17
unnamed: U1.P104 (IO_L1N_VREF_1), X2.19
unnamed: U1.P105 (IO_L1P_1), X2.20
unnamed: LED1.C, R78.2
unnamed: LED2.C, R79.2
unnamed: LED3.C, R80.2
unnamed: LED4.C, R81.2
unnamed: LED5.C, R82.2
unnamed: LED1.A, U1.P74 (IO_L74N_DOUT_BUSY_1)
unnamed: LED2.A, U1.P75 (IO_L74P_AWAKE_1)
unnamed: LED3.A, U1.P78 (IO_L47N_1)
unnamed: LED4.A, U1.P79 (IO_L47P_1)
unnamed: LED5.A, U1.P80 (IO_L46N_1)
VCCINT: X2.4; also elsewhere on the board

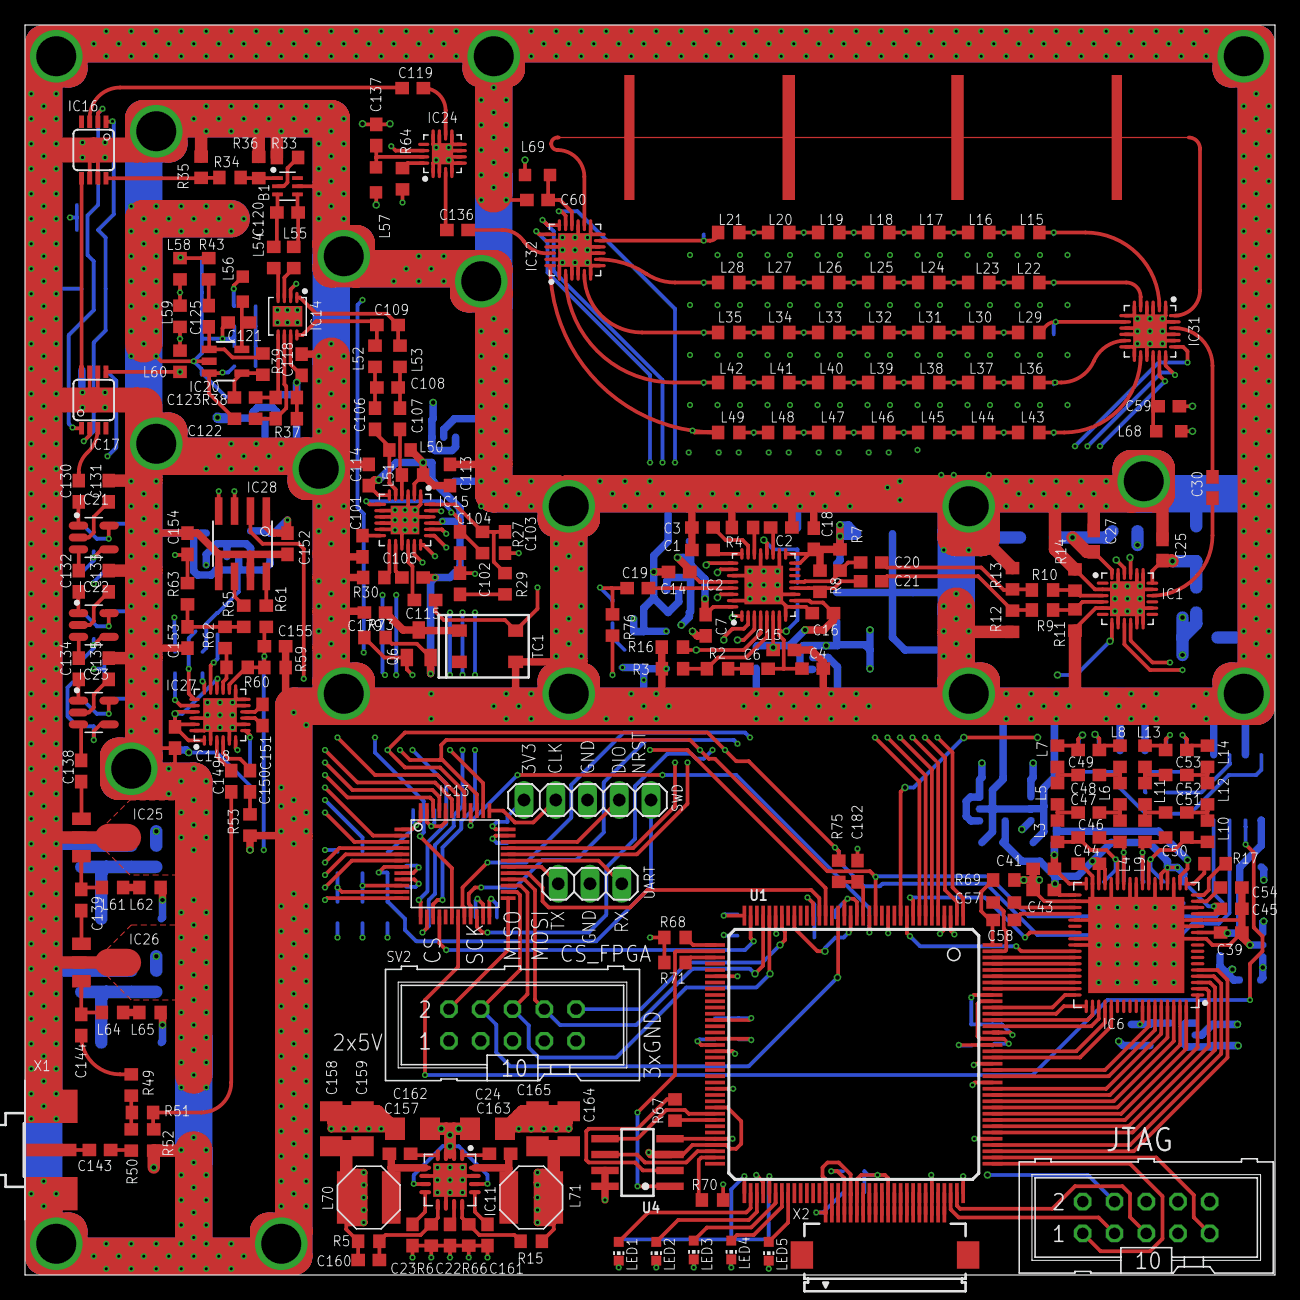
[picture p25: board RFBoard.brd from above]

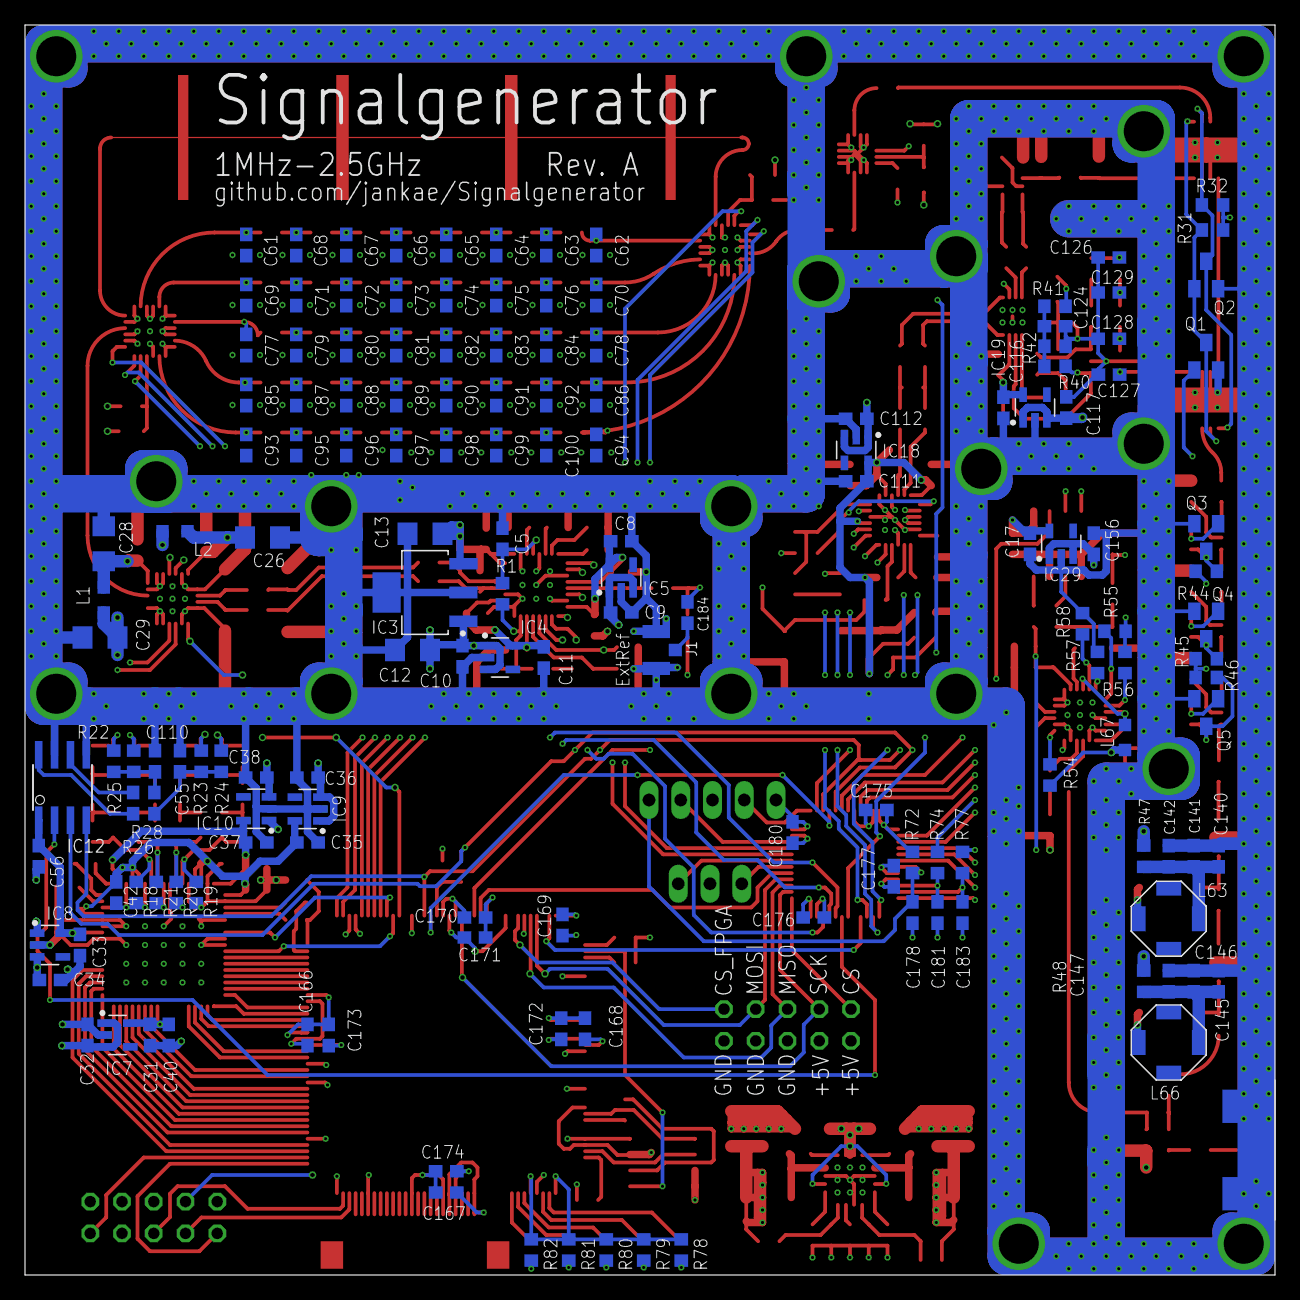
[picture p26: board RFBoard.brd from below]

Board: 4 copper layers, 100.0 x 100.0 mm, 390 parts (153 on the bottom side), 306 nets.

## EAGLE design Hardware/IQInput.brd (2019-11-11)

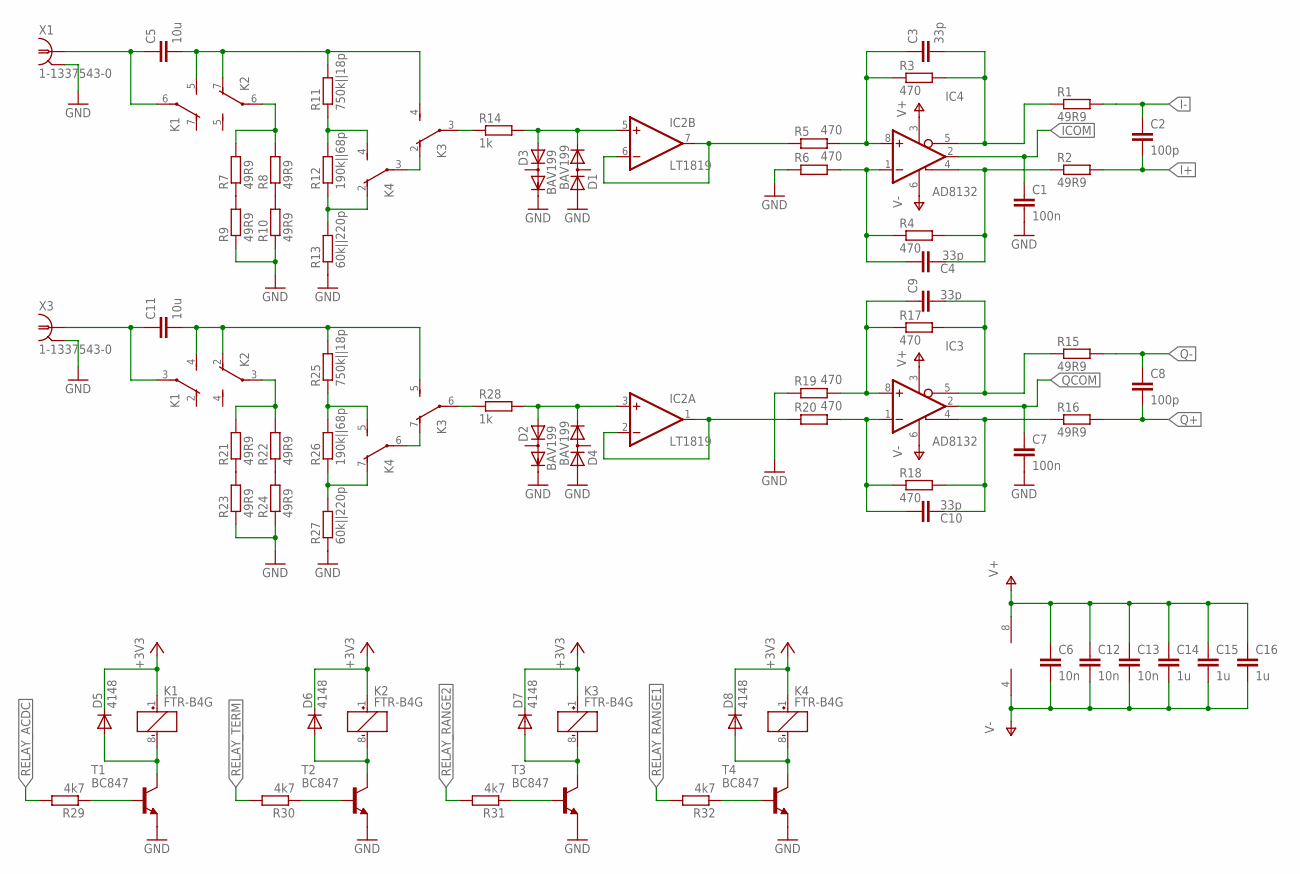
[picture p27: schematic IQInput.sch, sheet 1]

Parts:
C1, C7: 100n; C0603
C2, C8: 100p; C0603
C3, C4, C9, C10: 33p; C0603
C5, C11: 10u; C1206
C6, C12, C13: 10n; C0603
C14, C15, C16: 1u; C0603
D1, D2, D3, D4: BAV199; SOT23
D5, D6, D7, D8: 4148; MINIMELF
IC2: LT1819; SO08
IC3, IC4: AD8132; MSOP8
K1, K2, K3, K4: FTR-B4G
R1, R2, R15, R16: 49R9; R0603
R3, R4, R5, R6, R17, R18, R19, R20: 470; R0603
R7, R8, R9, R10, R21, R22, R23, R24: 49R9; R1206
R11, R25: 750k||18p; R0603
R12, R26: 190k||68p; R0603
R13, R27: 60k||220p; R0603
R14, R28: 1k; R0603
R29, R30, R31, R32: 4k7; R0603
T1, T2, T3, T4: BC847; SOT23
X1, X3: 1-1337543-0; AMP_227161

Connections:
+3V3: D5.C, D6.C, D7.C, D8.C, K1.1 (+), K2.1 (+), K3.1 (+), K4.1 (+); also elsewhere on the board
GND: C1.2, C7.2, D1.1 (A), D2.2 (C), D3.2 (C), D4.1 (A), R6.1, R9.1, R10.1, R13.1, R19.1, R23.1, R24.1, R27.1, T1.2 (E), T2.2 (E), T3.2 (E), T4.2 (E), X1.2, X3.2; also elsewhere on the board
I+: C2.2, R2.2; also elsewhere on the board
I-: C2.1, R1.2; also elsewhere on the board
ICOM: C1.1, IC4.2 (VOCM); also elsewhere on the board
unnamed: C4.2, IC4.4 (+OUT), R2.1, R4.2
unnamed: C5.1, K1.6, X1.1
unnamed: C4.1, IC4.1 (-IN), R4.1, R6.2
unnamed: C3.1, IC4.8 (+IN), R3.1, R5.2
unnamed: C3.2, IC4.5 (-OUT), R1.1, R3.2
unnamed: C5.2, K1.5 (S), K2.7 (O), K3.4 (S), R11.2
unnamed: R8.1, R10.2
unnamed: R7.1, R9.2
unnamed: K2.6, R7.2, R8.2
unnamed: K4.4 (S), R11.1, R12.2
unnamed: K4.2 (O), R12.1, R13.2
unnamed: K3.2 (O), K4.3
unnamed: K3.3, R14.1
unnamed: D1.2 (C), D3.1 (A), IC2.5 (+IN), R14.2
unnamed: IC2.6 (-IN), IC2.7 (OUT), R5.1
unnamed: C10.2, IC3.4 (+OUT), R16.1, R18.2
unnamed: C10.1, IC3.1 (-IN), R18.1, R20.2
unnamed: C9.1, IC3.8 (+IN), R17.1, R19.2
unnamed: C9.2, IC3.5 (-OUT), R15.1, R17.2
unnamed: C11.1, K1.3, X3.1
unnamed: C11.2, K1.4 (S), K2.2 (O), K3.5 (S), R25.2
unnamed: R22.1, R24.2
unnamed: R21.1, R23.2
unnamed: K2.3, R21.2, R22.2
unnamed: K4.5 (S), R25.1, R26.2
unnamed: K4.7 (O), R26.1, R27.2
unnamed: K3.7 (O), K4.6
unnamed: K3.6, R28.1
unnamed: D2.1 (A), D4.2 (C), IC2.3 (+IN), R28.2
unnamed: IC2.1 (OUT), IC2.2 (-IN), R20.1
unnamed: D5.A, K1.8 (-), T1.3 (C)
unnamed: R29.1, T1.1 (B)
unnamed: D6.A, K2.8 (-), T2.3 (C)
unnamed: R30.1, T2.1 (B)
unnamed: D7.A, K3.8 (-), T3.3 (C)
unnamed: R31.1, T3.1 (B)
unnamed: D8.A, K4.8 (-), T4.3 (C)
unnamed: R32.1, T4.1 (B)
Q+: C8.2, R16.2; also elsewhere on the board
Q-: C8.1, R15.2; also elsewhere on the board
QCOM: C7.1, IC3.2 (VOCM); also elsewhere on the board
RELAY_ACDC: R29.2; also elsewhere on the board
RELAY_RANGE1: R32.2; also elsewhere on the board
RELAY_RANGE2: R31.2; also elsewhere on the board
RELAY_TERM: R30.2; also elsewhere on the board
V+: C6.1, C12.1, C13.1, C14.1, C15.1, C16.1, IC2.8 (V+), IC3.3 (V+), IC4.3 (V+); also elsewhere on the board
V-: C6.2, C12.2, C13.2, C14.2, C15.2, C16.2, IC2.4 (V-), IC3.6 (V-), IC4.6 (V-); also elsewhere on the board

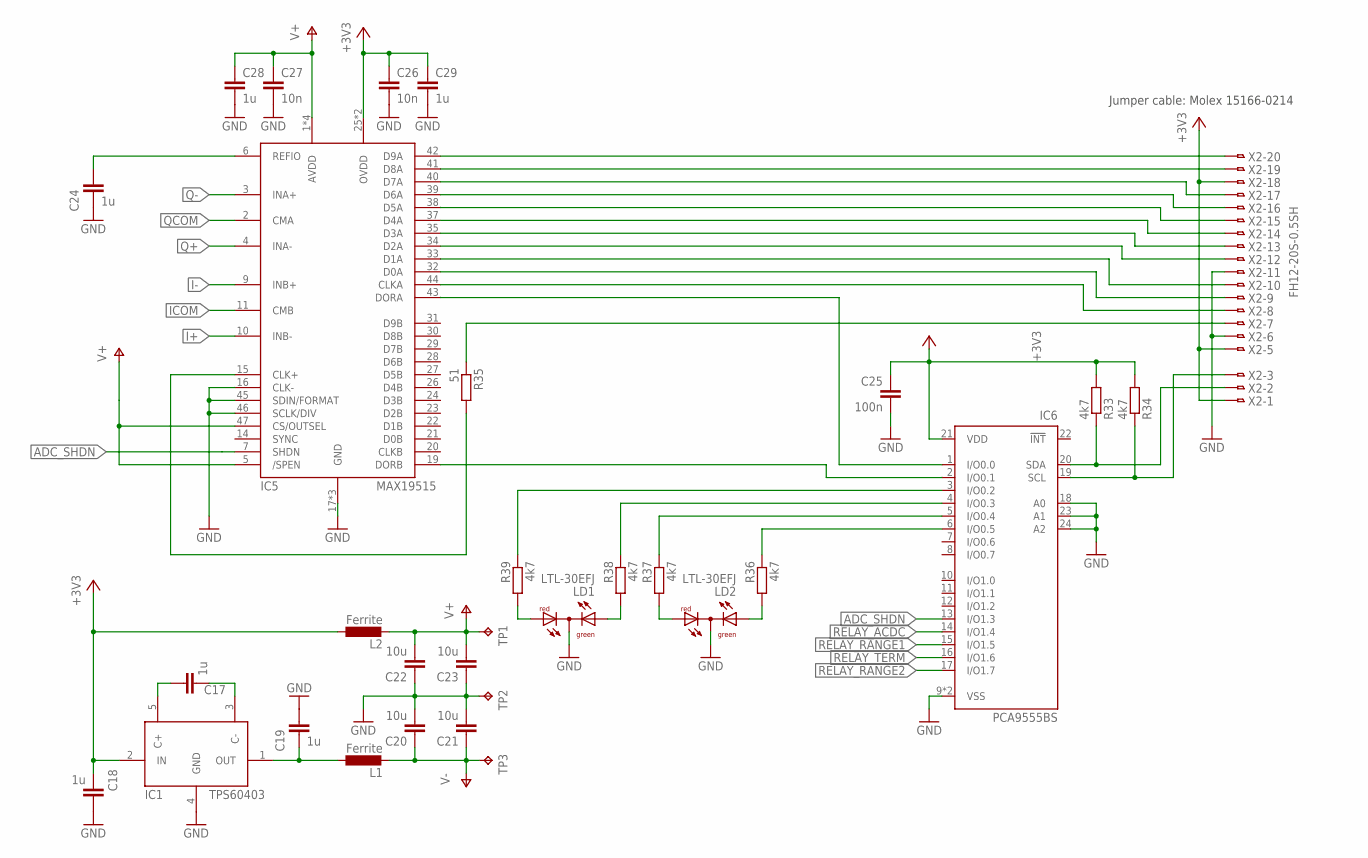
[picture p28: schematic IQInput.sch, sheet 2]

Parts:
C17, C18, C19, C24, C28, C29: 1u; C0603
C20, C21, C22, C23: 10u; C1206
C25: 100n; C0603
C26, C27: 10n; C0603
IC1: TPS60403; SOT23-5
IC5: MAX19515; QFN50P700X700X75-49T550N
IC6: PCA9555BS; HVQFN24
L1, L2: Ferrite; L2012C
LD1, LD2: LTL-30EFJ; DUOLED-C-5MM
R33, R34, R36, R37, R38, R39: 4k7; R0603
R35: 51; R0603
TP1, TP2, TP3: TPTP15R; TP15R
X2: FH12-20S-0.5SH

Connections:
+3V3: C18.2, C25.1, C26.1, C29.1, IC1.2 (IN), IC5.25 (OVDD), IC5.36 (OVDD), IC6.21 (VDD), L2.1, R33.2, R34.2, X2.1, X2.5, X2.18; also elsewhere on the board
ADC_SHDN: IC5.7 (SHDN), IC6.13 (I/O1.3)
GND: C18.1, C19.1, C20.2, C21.2, C22.1, C23.1, C24.2, C25.2, C26.2, C27.2, C28.2, C29.2, IC1.4 (GND), IC5.16 (CLK-), IC5.17 (GND), IC5.18 (GND), IC5.45 (SDIN/FORMAT), IC5.46 (SCLK/DIV), IC5.49 (GND), IC6.9 (VSS), IC6.18 (A0), IC6.23 (A1), IC6.24 (A2), IC6.TH (VSS), LD1.C, LD2.C, TP2.TP, X2.6, X2.11; also elsewhere on the board
I+: IC5.10 (INB-); also elsewhere on the board
I-: IC5.9 (INB+); also elsewhere on the board
ICOM: IC5.11 (CMB); also elsewhere on the board
unnamed: C17.1, IC1.5 (C+)
unnamed: C17.2, IC1.3 (C-)
unnamed: C19.2, IC1.1 (OUT), L1.1
unnamed: C24.1, IC5.6 (REFIO)
unnamed: IC5.43 (DORA), IC6.1 (I/O0.0)
unnamed: IC6.19 (SCL), R34.1, X2.3
unnamed: IC5.42 (D9A), X2.20
unnamed: IC5.41 (D8A), X2.19
unnamed: IC5.40 (D7A), X2.17
unnamed: IC5.39 (D6A), X2.16
unnamed: IC5.38 (D5A), X2.15
unnamed: IC5.37 (D4A), X2.14
unnamed: IC5.35 (D3A), X2.13
unnamed: IC5.34 (D2A), X2.12
unnamed: IC5.33 (D1A), X2.10
unnamed: IC5.32 (D0A), X2.9
unnamed: IC5.44 (CLKA), X2.8
unnamed: R35.1, X2.7
unnamed: IC5.15 (CLK+), R35.2
unnamed: IC6.20 (SDA), R33.1, X2.2
unnamed: IC5.19 (DORB), IC6.2 (I/O0.1)
unnamed: LD1.AR, R39.2
unnamed: LD1.AX (AG), R38.2
unnamed: LD2.AR, R37.2
unnamed: LD2.AX (AG), R36.2
unnamed: IC6.3 (I/O0.2), R39.1
unnamed: IC6.4 (I/O0.3), R38.1
unnamed: IC6.5 (I/O0.4), R37.1
unnamed: IC6.6 (I/O0.5), R36.1
Q+: IC5.4 (INA-); also elsewhere on the board
Q-: IC5.3 (INA+); also elsewhere on the board
QCOM: IC5.2 (CMA); also elsewhere on the board
RELAY_ACDC: IC6.14 (I/O1.4); also elsewhere on the board
RELAY_RANGE1: IC6.15 (I/O1.5); also elsewhere on the board
RELAY_RANGE2: IC6.17 (I/O1.7); also elsewhere on the board
RELAY_TERM: IC6.16 (I/O1.6); also elsewhere on the board
V+: C22.2, C23.2, C27.1, C28.1, IC5.1 (AVDD), IC5.5 (/SPEN), IC5.12 (AVDD), IC5.13 (AVDD), IC5.47 (CS/OUTSEL), IC5.48 (AVDD), L2.2, TP1.TP; also elsewhere on the board
V-: C20.1, C21.1, L1.2, TP3.TP; also elsewhere on the board

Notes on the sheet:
Jumper cable: Molex 15166-0214



Board: 4 copper layers, 50.0 x 50.0 mm, 100 parts (2 on the bottom side), 82 nets.

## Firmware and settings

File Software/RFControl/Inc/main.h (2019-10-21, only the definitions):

#define DET_EN_Pin GPIO_PIN_13
#define DET_EN_GPIO_Port GPIOC
#define DET_SCI4_Pin GPIO_PIN_14
#define DET_SCI4_GPIO_Port GPIOC
#define DB15_3_Pin GPIO_PIN_15
#define DB15_3_GPIO_Port GPIOC
#define DB15_2_Pin GPIO_PIN_0
#define DB15_2_GPIO_Port GPIOF
#define DB15_1_Pin GPIO_PIN_1
#define DB15_1_GPIO_Port GPIOF
#define EN_DIRECT_Pin GPIO_PIN_2
#define EN_DIRECT_GPIO_Port GPIOA
#define EN_INTREF_Pin GPIO_PIN_3
#define EN_INTREF_GPIO_Port GPIOA
#define ADF_MUX_Pin GPIO_PIN_4
#define ADF_MUX_GPIO_Port GPIOA
#define ADF_CE_Pin GPIO_PIN_5
#define ADF_CE_GPIO_Port GPIOA
#define FPGA_CS_Pin GPIO_PIN_6
#define FPGA_CS_GPIO_Port GPIOA
#define MIX_EN_Pin GPIO_PIN_0
#define MIX_EN_GPIO_Port GPIOB
#define OFFSET_CS_Pin GPIO_PIN_1
#define OFFSET_CS_GPIO_Port GPIOB
#define SYNTH_RF_EN_Pin GPIO_PIN_2
#define SYNTH_RF_EN_GPIO_Port GPIOB
#define SYNTH_MUX_Pin GPIO_PIN_10
#define SYNTH_MUX_GPIO_Port GPIOB
#define SYNTH_LE_Pin GPIO_PIN_11
#define SYNTH_LE_GPIO_Port GPIOB
#define FPGA_RESET_Pin GPIO_PIN_8
#define FPGA_RESET_GPIO_Port GPIOA
#define SYNTH_CE_Pin GPIO_PIN_11
#define SYNTH_CE_GPIO_Port GPIOA
#define SYNTH_LD_Pin GPIO_PIN_12
#define SYNTH_LD_GPIO_Port GPIOA
#define ADF_LE_Pin GPIO_PIN_15
#define ADF_LE_GPIO_Port GPIOA
#define DBM_CS_Pin GPIO_PIN_6
#define DBM_CS_GPIO_Port GPIOB
#define DET_SCI3_Pin GPIO_PIN_7
#define DET_SCI3_GPIO_Port GPIOB
#define DET_SCI1_Pin GPIO_PIN_8
#define DET_SCI1_GPIO_Port GPIOB
#define DET_SCI2_Pin GPIO_PIN_9
#define DET_SCI2_GPIO_Port GPIOB

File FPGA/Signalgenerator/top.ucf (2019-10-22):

CONFIG VCCAUX=3.3;
NET "CLK" LOC = P23;
NET "CLK" PERIOD = 100ns;


NET "CLK" IOSTANDARD = LVCMOS33;
NET "RESET" IOSTANDARD = LVCMOS33;
NET "SPI_EXT_CS" IOSTANDARD = LVCMOS33;
NET "SPI_EXT_MOSI" IOSTANDARD = LVCMOS33;
NET "SPI_EXT_SCK" IOSTANDARD = LVCMOS33;
NET "SPI_INT_CS" IOSTANDARD = LVCMOS33;
NET "SPI_INT_MOSI" IOSTANDARD = LVCMOS33;
NET "SPI_INT_SCK" IOSTANDARD = LVCMOS33;
NET "MOD_EN" IOSTANDARD = LVCMOS33;
NET "SPI_EXT_MISO" IOSTANDARD = LVCMOS33;
NET "SELIQ" IOSTANDARD = LVCMOS33;
NET "DORI" IOSTANDARD = LVCMOS33;
NET "SPI_INT_MISO" IOSTANDARD = LVCMOS33;
NET "I[11]" IOSTANDARD = LVCMOS33;
NET "I[10]" IOSTANDARD = LVCMOS33;
NET "I[9]" IOSTANDARD = LVCMOS33;
NET "I[8]" IOSTANDARD = LVCMOS33;
NET "I[7]" IOSTANDARD = LVCMOS33;
NET "I[6]" IOSTANDARD = LVCMOS33;
NET "I[5]" IOSTANDARD = LVCMOS33;
NET "I[4]" IOSTANDARD = LVCMOS33;
NET "I[3]" IOSTANDARD = LVCMOS33;
NET "I[2]" IOSTANDARD = LVCMOS33;
NET "I[1]" IOSTANDARD = LVCMOS33;
NET "I[0]" IOSTANDARD = LVCMOS33;
NET "Q[11]" IOSTANDARD = LVCMOS33;
NET "Q[10]" IOSTANDARD = LVCMOS33;
NET "Q[9]" IOSTANDARD = LVCMOS33;
NET "Q[8]" IOSTANDARD = LVCMOS33;
NET "Q[7]" IOSTANDARD = LVCMOS33;
NET "Q[6]" IOSTANDARD = LVCMOS33;
NET "Q[5]" IOSTANDARD = LVCMOS33;
NET "Q[4]" IOSTANDARD = LVCMOS33;
NET "Q[3]" IOSTANDARD = LVCMOS33;
NET "Q[2]" IOSTANDARD = LVCMOS33;
NET "Q[1]" IOSTANDARD = LVCMOS33;
NET "Q[0]" IOSTANDARD = LVCMOS33;
NET "SW2_CTL[2]" IOSTANDARD = LVCMOS33;
NET "SW2_CTL[1]" IOSTANDARD = LVCMOS33;
NET "SW2_CTL[0]" IOSTANDARD = LVCMOS33;
NET "SW1_CTL[2]" IOSTANDARD = LVCMOS33;
NET "SW1_CTL[1]" IOSTANDARD = LVCMOS33;
NET "SW1_CTL[0]" IOSTANDARD = LVCMOS33;
NET "LED[4]" IOSTANDARD = LVCMOS33;
NET "LED[3]" IOSTANDARD = LVCMOS33;
NET "LED[2]" IOSTANDARD = LVCMOS33;
NET "LED[1]" IOSTANDARD = LVCMOS33;
NET "LED[0]" IOSTANDARD = LVCMOS33;

NET "ADC_SAMPLE_CLK" IOSTANDARD = LVCMOS33;
NET "ADC_DCLK" IOSTANDARD = LVCMOS33;
NET "ADC_DATA[0]" IOSTANDARD = LVCMOS33;
NET "ADC_DATA[1]" IOSTANDARD = LVCMOS33;
NET "ADC_DATA[2]" IOSTANDARD = LVCMOS33;
NET "ADC_DATA[3]" IOSTANDARD = LVCMOS33;
NET "ADC_DATA[4]" IOSTANDARD = LVCMOS33;
NET "ADC_DATA[5]" IOSTANDARD = LVCMOS33;
NET "ADC_DATA[6]" IOSTANDARD = LVCMOS33;
NET "ADC_DATA[7]" IOSTANDARD = LVCMOS33;
NET "ADC_DATA[8]" IOSTANDARD = LVCMOS33;
NET "ADC_DATA[9]" IOSTANDARD = LVCMOS33;

NET "SDA" IOSTANDARD = LVCMOS33;
NET "SCL" IOSTANDARD = LVCMOS33;

NET "RESET" LOC = P24;
NET "SPI_EXT_CS" LOC = P30;
NET "SPI_EXT_MOSI" LOC = P33;
NET "SPI_EXT_SCK" LOC = P21;
NET "SPI_INT_CS" LOC = P35;
NET "SPI_INT_MOSI" LOC = P15;
NET "SPI_INT_SCK" LOC = P17;

NET "MOD_EN" LOC = P11;
NET "SELIQ" LOC = P10;
NET "SPI_EXT_MISO" LOC = P32;
NET "SPI_INT_MISO" LOC = P16;
NET "I[11]" LOC = P142;
NET "I[10]" LOC = P141;
NET "I[9]" LOC = P140;
NET "I[8]" LOC = P139;
NET "I[7]" LOC = P138;
NET "I[6]" LOC = P137;
NET "I[5]" LOC = P134;
NET "I[4]" LOC = P133;
NET "I[3]" LOC = P132;
NET "I[2]" LOC = P131;
NET "I[1]" LOC = P127;
NET "I[0]" LOC = P126;
NET "Q[11]" LOC = P124;
NET "Q[9]" LOC = P121;
NET "Q[7]" LOC = P119;
NET "Q[8]" LOC = P120;
NET "Q[6]" LOC = P118;
NET "Q[5]" LOC = P117;
NET "Q[4]" LOC = P116;
NET "Q[3]" LOC = P115;
NET "Q[2]" LOC = P114;
NET "Q[1]" LOC = P112;
NET "Q[0]" LOC = P111;
NET "SW1_CTL[0]" LOC = P1;
NET "SW1_CTL[1]" LOC = P2;
NET "SW1_CTL[2]" LOC = P5;
NET "SW2_CTL[2]" LOC = P8;
NET "SW2_CTL[0]" LOC = P6;
NET "SW2_CTL[1]" LOC = P7;
NET "LED[4]" LOC = P80;
NET "LED[3]" LOC = P79;
NET "LED[2]" LOC = P78;
NET "LED[1]" LOC = P75;
NET "LED[0]" LOC = P74;
NET "Q[10]" LOC = P123;
NET "DORI" LOC = P9;

NET "ADC_SAMPLE_CLK" LOC = P92;
NET "ADC_DCLK" LOC = P93;
NET "ADC_DATA[0]" LOC = P94;
NET "ADC_DATA[1]" LOC = P95;
NET "ADC_DATA[2]" LOC = P97;
NET "ADC_DATA[3]" LOC = P98;
NET "ADC_DATA[4]" LOC = P99;
NET "ADC_DATA[5]" LOC = P100;
NET "ADC_DATA[6]" LOC = P101;
NET "ADC_DATA[7]" LOC = P102;
NET "ADC_DATA[8]" LOC = P104;
NET "ADC_DATA[9]" LOC = P105;

NET "SDA" LOC = P87;
NET "SCL" LOC = P88;

# PlanAhead Generated physical constraints 

NET "CLK_DAC_N" LOC = P143;
NET "CLK_DAC_P" LOC = P144;

# PlanAhead Generated IO constraints 

NET "CLK_DAC_N" IOSTANDARD = DIFF_SSTL3_II;
NET "CLK_DAC_P" IOSTANDARD = DIFF_SSTL3_II;

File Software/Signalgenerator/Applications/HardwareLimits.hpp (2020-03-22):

#pragma once
#include <cstdint>

namespace HardwareLimits {

static constexpr uint32_t MinFrequency = 5000000;
static constexpr uint32_t MaxFrequency = 2100000000;
static constexpr int16_t MaxOutputLevel = 2000;
static constexpr int16_t MinOutputLevel = -6000;

static constexpr uint32_t FPGA_CLK = 200000000;
static constexpr uint32_t FIRCLKPeriods = 6;
static constexpr uint32_t MaxFIRRate = FPGA_CLK / FIRCLKPeriods;
static constexpr uint8_t FIRTaps = 71;
static constexpr uint8_t BitsModSrcPinc = 27;
static constexpr uint8_t BitsModSrcExposed = 20;
static constexpr uint8_t BitsQAMSampleratePinc = 32;
static constexpr uint8_t BitsQAMSamplerateExposed = 32;
static constexpr uint8_t BitsFMDDSPinc = 32;
static constexpr uint16_t MaxSrcValue = 4095;
static constexpr uint16_t MaxFMDeviationSetting = 65535;
static constexpr uint32_t ExtSamplerate = MaxFIRRate;
static constexpr uint32_t MaxExtModInputVoltage = 10000000;
static constexpr int32_t MaxExtModADCVoltage = 750000;
static constexpr int16_t MaxExtModADCValue = 512;

static constexpr uint32_t MaxModSrcFreq = ((uint64_t) FPGA_CLK
		* ((1ULL << BitsModSrcExposed) - 1)) / (1ULL << BitsModSrcPinc);
static constexpr uint32_t MaxFMDeviation = ((uint64_t) FPGA_CLK * MaxSrcValue
		* MaxFMDeviationSetting) / (1ULL << BitsFMDDSPinc);

}

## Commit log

2019-05-28 Partial schematic
    [RFBoard.sch]
2019-05-30 Heterodyne path sheet
    [RFBoard.sch]
2019-06-01 RF part of schematic finished, placed most components on PCB
    [RFBoard.brd, RFBoard.sch]
2019-06-01 Almost all RF routing
    [RFBoard.brd, RFBoard.sch]
2019-06-02 FPGA + power supply added
    [RFBoard.brd, RFBoard.sch]
2019-06-02 MCU added
    [RFBoard.brd, RFBoard.sch]
2019-06-03 Routing of schematic completed
    [RFBoard.brd, RFBoard.sch]
2019-06-04 Via stitching, missing connections, FPGA pins to FFC connector
    [RFBoard.brd, RFBoard.sch]
2019-06-05 Silkscreen, MOD_EN wire
    [RFBoard.brd, RFBoard.sch]
2019-06-05 PCB finished
    [RFBoard.brd, RFBoard.sch]
2019-06-08 MAX2871/ADF4360 drivers
2019-06-09 MCP48X2 driver, RF path logic
2019-06-10 GUI copy and adjustments for menu from battery-sim
    [New_configuration.cfg]
2019-06-12 Remove application code from battery-sim, added item chooser as menu entry
2019-06-25 Hardfault handler output, button input bugfixing, menuvalue with input dialog
    [startup.cpp, touch.cpp]
2019-06-26 bugfixes, MenuAction, main screen layout
    [Generator.cpp, app.cpp, display.cpp]
2019-06-29 untested implementation of SPI protocol between frontpanel and RF board
2019-06-29 Switched to correct MCU version, bugfixes in PLL drivers
    [RF.cpp, RFControl.ioc, app.cpp]
2019-06-29 PLL loop filter values changed
    [RFBoard.brd, RFBoard.csv, RFBoard.ods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]
2019-07-01 Value changes amplitude control feedback loop
    [RFBoard.brd, RFBoard.sch]
2019-07-05 Bugfix: Lockissue + basic FM modulation
    [Generator.cpp, RF.cpp, app.cpp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]
2019-07-13 Calibration of amplitude + persistent storage in last FLASH page
2019-07-13 Pictures/block diagram of RF board
2019-07-13 Ignore 3D CAD file
2019-07-23 USB audio experiments + added (almost useless) balance calibration
2019-10-10 SevenSegment changeable with arrow keys/encoder
2019-10-11 Schematic + Routing of IQ input board
    [IQInput.brd, IQInput.sch]
2019-10-11 Stepfile for display adapter
    [DisplayAdapter.stp]
2019-10-12 FIR filter tests with multiplexed multipliers
2019-10-13 Basic pulse shaping working (no GUI configuration yet)
    [Signalgenerator Release.cfg]
2019-10-13 Bugfix: samples per symbol off by one
2019-10-14 Reworked menu structure for modulation settings
    [Generator.cpp, SPIProtocol.cpp, display.cpp]
2019-10-16 Added value to input protection resistor
    [IQInput.brd, IQInput.sch]
2019-10-16 Specified values
    [IQInput.brd, IQInput.sch]
2019-10-17 Made room for on/off switch
    [DisplayAdapter.stp]
2019-10-17 Capsulated FPGA access, buttons for RF/modulation on/off
2019-10-20 Added testpoints, changes to silkscreen, created Gerber
    [IQInput.brd, IQInput.sch]
2019-10-21 Switched to 10MHz ref clk as FPGA clk, added reset, ADC sampling for external I/Q input
    [top.ucf]
2019-10-21 CubeMX update, added FPGA reset
    [RFControl Release.cfg]
2019-10-21 Check communication with RF board at startup
2019-10-22 Passing external modulation signals through gluelogic
2019-10-28 External modulation added to SPI protocol on master side
2019-11-03 Slight improvements to balance calibration
2019-11-09 Bugfixes: external modulation + I2C master in FPGA
    [Generator.cpp, SPIProtocol.cpp]
2019-11-11 Fixed external modulation input, balance calibration. Preparations for skew calibration
    [Calibration.cpp, Generator.cpp, SPIProtocol.cpp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]
2019-11-11 Part values corrected
    [IQInput.brd, IQInput.sch]
2019-11-11 External modulation lowpass + bugfix constellation scaling
    [FPGA.cpp, Generator.cpp, HardwareLimits.hpp]
2019-11-11 IQ input board startup check and overload reporting
2019-11-16 Improved calibration routines
2019-11-18 Pictures of assembled device
2019-11-18 BOM IQ input board
    [IQInput.csv, IQInput.ods]
2020-03-21 External modulation input usable as modulation source
    [RFBoard.brd, RFBoard.sch]
2020-03-22 Bugfixes: FPGA I2C SDA glitch, negative offsets for external modulation
    [HardwareLimits.hpp, SPIProtocol.cpp]

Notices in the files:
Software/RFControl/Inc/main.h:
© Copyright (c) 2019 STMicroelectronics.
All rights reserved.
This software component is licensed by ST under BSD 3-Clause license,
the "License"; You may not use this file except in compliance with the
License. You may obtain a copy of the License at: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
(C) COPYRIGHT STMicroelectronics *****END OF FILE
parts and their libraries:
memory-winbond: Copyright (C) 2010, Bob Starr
